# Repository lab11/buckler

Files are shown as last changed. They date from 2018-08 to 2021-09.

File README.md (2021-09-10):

Berkeley Buckler
================



A development board for teaching embedded systems.

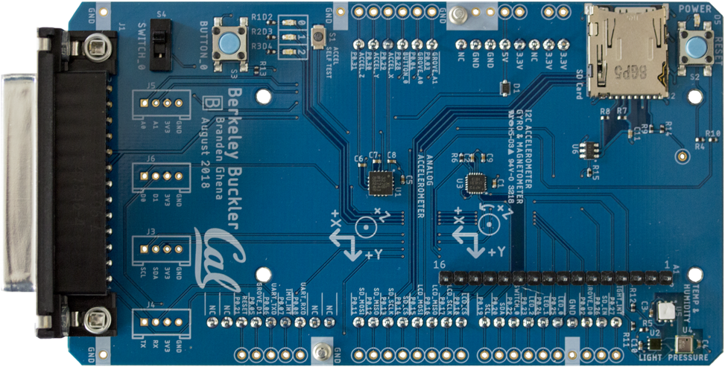
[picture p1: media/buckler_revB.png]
Buckler PCB


### Getting Started

 1. Clone this repository and update the submodule

```
  $ git clone https://github.com/lab11/buckler.git --recursive
  $ git subomdule update --init --recursive
```

 2. Build an example application

```
  $ cd software/apps/blink/
  $ make
```

You should see results similar to

```
BUILD OPTIONS:
  Chip        nrf52832
  RAM         64 kB
  FLASH       512 kB
  SDK         15
  SoftDevice  s132 6.0.0
  Board       Buckler_revB

 DIR        _build
 CC main.c ...
 ... (many more CCs) ...
 LD _build/blink_sdk15_s132.elf
 HEX _build/blink_sdk15_s132.hex
 BIN _build/blink_sdk15_s132.hex
 SIZE _build/blink_sdk15_s132.elf
 text    data    bss     dec    hex   filename
 37672   2548   2624   42844   a75c   _build/blink_sdk15_s132.elf
```

 3. Load the example application (be sure to connect your Buckler board)

```
  $ make flash
```

The three LEDS (red, yellow, and blue) on Buckler should begin a blinking
sequence.

### Build Options

Several make directives exist for convenience of performing common operations.

 * **flash** - Upload code to the attached board over JTAG. Also builds code if
               necessary.
 * **rtt** - Open two additional terminals, one starting a JTAG connection and
             the other with an RTT terminal.
 * **gdb** - Open two additional terminals, one starting a GDB server and the
		     the other with a GDB session.
 * **debug** - Build application in unoptimized debug mode (with `-g` and `-O0`).
 * **flash_debug** - Upload debug version of code to the attached board over JTAG.
				     Also builds the debug version of code if necessary.
 * **erase** - Erase all code from the attached board over JTAG.
 * **flash_softdevice** - Upload the appropriate softdevice to the board over JTAG.
						  `make flash` automatically runs this command.
 * **clean** - Remove all built output.
 * **size** - Print size of built application text and data segments.
 * **lst** - Generate an assembly listing of the built code.

### Directory Structure

```
├── hardware
│   └── <Various hardware revisions>
│       ├── <PDF version of schematic and layout>
│       ├── <Eagle schematic and layout files>
│       └── <Zipped assembly files>
├── media
│   └── <Images used in repo>
└── software
    ├── apps
    │   └── <Various applications>
    │       ├── <Code for application>
    │       └── <Makefile for application>
    ├── boards
    │   └── <Board-specific headers and Makefiles>
    ├── libraries
    │   └── <Various libraries>
    ├── nrf5x-base
    │   └── <Submodule: build tools and files for nRF projects>
    └── tools
        └── <Tools for Travis-CI use>
```

### Project Repositories

If you are using Buckler for a project, we recommend you include it as a
submodule in your own repository. An example of how to do so can be found in:
[buckler-external-repo](https://github.com/brghena/buckler-external-repo)

### Software Requirements

In order to get code compiling and loading over JTAG, you'll need at least two tools.

**JLinkExe** should be installed from [here](https://www.segger.com/downloads/jlink).
You want to the "J-Link Software and Documentation Pack". There are various packages
available depending on operating system.

**arm-none-eabi-gcc** is the cross-compiler version of GCC for building embedded ARM code.

  MacOS:
  ```
  $ brew tap ARMmbed/homebrew-formulae && brew update && brew install arm-none-eabi-gcc
  ```

  Ubuntu:
  ```
  $ sudo add-apt-repository ppa:team-gcc-arm-embedded/ppa && sudo apt update && sudo apt install gcc-arm-embedded
  ```

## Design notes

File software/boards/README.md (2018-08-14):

Boards
======

Platform-specific configurations and headers.

 * [Buckler revision A](../../hardware/rev_a/) - Buckler development shield revision A (obsolete)
 * [Buckler revision B](../../hardware/rev_b/) - Buckler development shield for [nRF52DK](http://infocenter.nordicsemi.com/index.jsp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)

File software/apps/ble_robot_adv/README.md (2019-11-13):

BLE Robot Template with Advertisements
================

Framework for using BLE advertisements + Kobuki
When button pressed, robot turns, and sends gyro readings over BLE advertisements

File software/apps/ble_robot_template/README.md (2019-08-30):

BLE Robot Template
================

Framework for using BLE + Kobuki

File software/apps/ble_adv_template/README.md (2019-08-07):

BLE Advertisement Template
===================

Starting point for creating a BLE advertisement application. This example uses
the Berkeley Buckler.

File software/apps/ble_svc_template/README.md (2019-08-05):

BLE Service Example
===================

This example code creates a custom service with readable and writable
characteristics which can be interacted with by a BLE master (such as a
smartphone).

The service and characteristic control LED0. Writing a 0x01 to the
characteristic turns the LED on, writing a 0x00 turns it off.

Using this application is essentially the same as any other Buckler app, with
`make flash` loading the application code and `make rtt` opening the RTT output
viewer.

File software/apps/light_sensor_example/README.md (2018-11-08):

Light Sensor Example
====================

Example that reads the MAX44009 light sensor. This uses the example code in
`libraries/max44009/` which was adapted from
[Permamote](https://github.com/lab11/permamote). The sensor data is read over
I2C.

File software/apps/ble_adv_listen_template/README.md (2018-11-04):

BLE RX Example
==============

Receives BLE advertisements. Advertisements are broadcast transmissions used to
discover the device which can also include up to 23 bytes of arbitrary payload
data.

This app can receive advertisements from anything, but is particularly looking
for another Buckler running the BLE TX Example application.

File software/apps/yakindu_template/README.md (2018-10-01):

Yakindu Template
================

Framework for using code generated by Yakindu statecharts.

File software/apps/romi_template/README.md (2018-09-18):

Robot Template
==============

Starting point for creating robot control code. This example uses the Kobuki
robot as well as the Berkeley Buckler.

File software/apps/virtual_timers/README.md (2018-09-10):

Virtual Timers
==============

The goal of this lab is to write a virtual timer library. You will use
one hardware timer to create a timer library that handles any number of timers.

The lab in order:
0) Read the timer and print it

1) Set up a single hardware timer interrupt and handle that interrupt

2) Create a timer library that can handle one timer at a time (with linked list)
    - Calculate time required for a time in ms and set up the timer
    - Insert into linked list
    - Call the callback function using function pointers

3) Add repeated mode to the timer library

4) Make two timers
    - Handle timers created out of earliest deadline order

5) Make N timers

6) Check for correctness in all cases
    - N timers firing very close to the same time (no timers should be dropped)
    - Add a very short timer to the list (does it keep firing?)
    - Remove timers from the list (do other timers keep firing?)

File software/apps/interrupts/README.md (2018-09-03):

Interrupts
=====

This is the starting application for Chapter 5 of the lab manual. The goal
is to explore and understand interrupts and related concepts such as wait for interrupt (WFI()), interrupt latency,
and interrupt priority/preemption/nesting.

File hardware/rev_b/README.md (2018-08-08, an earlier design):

Hardware Files
==============

The Berkeley Buckler was created in
[Eagle](https://www.autodesk.com/products/eagle/overview) and the `buckler.sch`
and `buckler.brd` files are Eagle schematic and board files respectively.
Schematic and board files can be viewed without Eagle in `buckler.pdf`.
`buckler_bom.xlsx` is the Bill of Materials (list of parts). It is also
provided as `txt` and `csv` files for convenience.

## Changes from prior revision
 * Change base board from the nRF52840DK to the nRF52DK (based on the nRF52832) due to availability
     * Reduced number of buttons, switches, and grove headers to deal with reduced number of pins
     * Removed connection to SD card detect signal to deal with reduced number of pins
     * Re-mapped signals to development kit pins
 * Made text bigger and added more test points
 * Shrunk board size a little

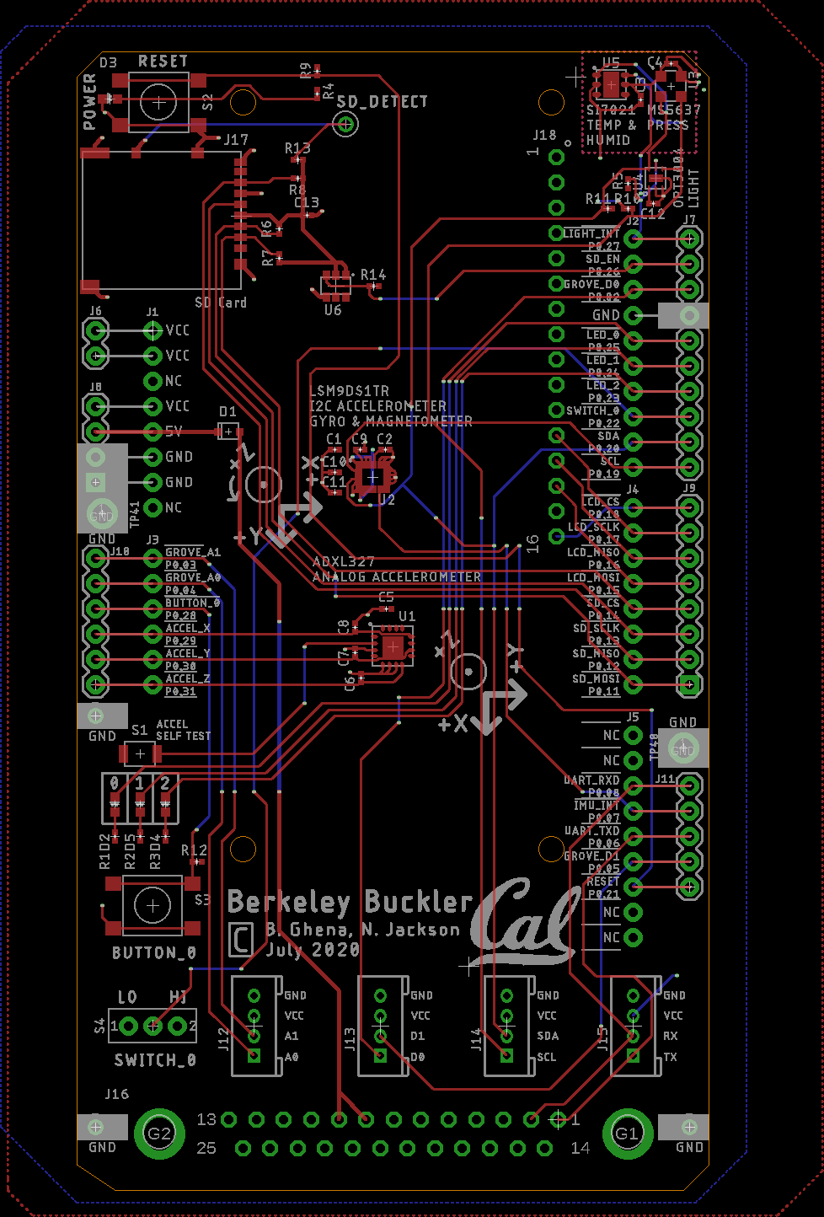
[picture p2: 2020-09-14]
hardware/rev_c/buckler_pcb.png

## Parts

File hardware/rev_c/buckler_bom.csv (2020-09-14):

# Bill of Materials
# Converted from {}
# Generated by bom_to_text.py
#
Qty | Value | Device | Package | Parts | Description | DESCRIPTION | DIGIKEY | MANUFACTURER | MOUSER | MPN
1 |  | DIODE_SCHOTTKYSOD323 | SOD323 | D1 |  | DIODE SCHOTTKY 30V 500MA SOD323 | B0530WS-FDICT-ND | Diodes Incorporated |  | B0530WS-7-F
4 |  | GROVE-CONNECTOR-DIP(4P-2.0) | HW4-2.0 | J12, J13, J14, J15 | 320110033 | Grove - Universal 4 pin connector |  | Seeed Studio | 713-110990030 | 110990030
1 |  | M02PTH | 1X02 | J6 | Header 2 |  | S1011EC-02-ND
1 |  | M04PTH | 1X04 | J8 | Header 4 |  | S1011EC-04-ND
1 |  | M05PTH | 1X05 | J11 | Header 5 |  | S1011EC-05-ND
2 |  | M06SIP | 1X06 | J3, J10 | Header 6 |  | S1011EC-06-ND
3 |  | M081X08 | 1X08 | J1, J4, J9 | Header 8 |  | S1011EC-08-ND
1 |  | M09PTH | 1X09 | J5 | Header 9 |  | S1011EC-09-ND
2 | M10 | M10 | M10 | J2, J7 | Header 10 |  | S1011EC-10-ND
2 | 100k | RESISTOR0402_RES | 0402_RES | R13, R14 | Resistor | RES SMD 100K OHM 1% 1/5W 0402 | 541-100KYCT-ND | Vishay Dale |  | CRCW0402100KFKEDHP
10 | 100nF | CAPACITOR0402_CAP | 0402_CAP | C3, C4, C5, C6, C7, C8, C9, C10, C11, C12 | SMD Capacitor | CAP CER 0.1UF 16V X7R 0402 | 490-4759-1-ND | Murata |  | GCM155R71C104KA55D
8 | 10k | RESISTOR0402_RES | 0402_RES | R5, R6, R7, R8, R9, R10, R11, R12 | Resistor | RES SMD 10K OHM 1% 1/16W 0402 | 1276-3431-1-ND | Samsung Electro-Mechanics |  | RC1005F103CS
2 | 10nF | CAPACITOR0402_CAP | 0402_CAP | C1, C2 | SMD Capacitor | CAP CER 10000PF 25V X7R 0402 | 399-1279-1-ND | KEMET |  | C0402C103J3RACTU
4 | 1k | RESISTOR0402_RES | 0402_RES | R1, R2, R3, R4 | Resistor | RES SMD 1K OHM 1% 1/16W 0402 | RMCF0402FT1K00CT-ND | Stackpole Electronics |  | RMCF0402FT1K00
1 | 4.7uF | CAPACITOR0402_CAP | 0402_CAP | C13 | SMD Capacitor | CAP CER 4.7UF 10V X5R 0402 | 1276-1480-1-ND | Samsung Electro-Mechanics |  | CL05A475KP5NRNC
1 | ADXL327 | ADXL327 | LFCSP-16 | U1 | ADXL327 3-Axis Analog Accelerometer | ACCELEROMETER 2G ANALOG 16LFCSP | ADXL327BCPZ-ND | Analog Devices Inc. |  | ADXL327BCPZ
1 | B3U-1000P | B3U-1000P | B3U-1000P | S1 | Switch | SWITCH TACTILE SPST-NO 0.05A 12V | SW1020CT-ND | Omron |  | B3U-1000P
1 | BLUE | LED0603 | LED-0603 | D4 | LED | LED BLUE CLEAR SMD | 160-1837-1-ND | Lite-On Inc. |  | LTST-C194TBKT
1 | DB25_5747846 | DB25_5747846 | DB25_5747846 | J16 |  | CONN D-SUB RCPT 25POS R/A SOLDER | A32126-ND | TE Connectivity AMP Connectors |  | 5747846-4
1 | DM3AT-SF-PEJM5 | DM3AT-SF-PEJM5 | DM3AT-SF-PEJM5 | J17 | CONN MICRO SD R/A PUSH-PUSH SMD | CONN MICRO SD CARD PUSH-PUSH R/A | HR1964CT-ND | Hirose Electric Co Ltd |  | DM3AT-SF-PEJM5
1 | GREEN | LED0603 | LED-0603 | D3 | LED | LED GREEN CLEAR CHIP SMD | 160-1435-1-ND | Lite-On Inc. |  | LTST-C190KGKT
1 | LSM9DS1TR | LSM9DS1TR | LGA-24_3X3P5X1_STM | U2 |  |  | 497-14946-1-ND |  |  | LSM9DS1TR
1 | MS5637-02BA03 | MS5637-02BA03 | 4-SMD | U3 | low power pressure sensor | SENSOR 17.4PSIA I2C 24B 4-QFN | 223-1199-1-ND | TE CONNECTIVITY |  | MS563702BA03-50
1 | NHD-0216KZWSERIAL | NHD-0216KZWSERIAL | NHD-0216KZW | J18 |  |  | NHD-0216KZW-AG5-ND, 952-3305-ND, 952-1862-ND
1 | OPT3004DNPR | OPT3004DNPR | DNP0006A | U4 |  |  | 296-53402-1-ND | Texas Instruments |  | OPT3004DNPR
2 | PTS645SM43SMTR92 | PTS645SM43SMTR92 | PTS645 | S2, S3 | Tactile Switch SPST-NO Top Actuated Surface Mount | SWITCH TACTILE SPST-NO 0.05A 12V | CKN9112CT-ND | C&K |  | PTS645SM43SMTR92 LFS
1 | RED | LED0603 | LED-0603 | D2 | LED | LED RED CLEAR CHIP SMD | 160-1436-1-ND | Lite-On Inc. |  | LTST-C190KRKT
1 | SI7021-A20-GM1 | SI7021-A20-GM1 | DFN-6/3MM | U5 | IC TEMP SENSOR RH 2% DFN | SENS HUMI/TEMP 3.6V I2C 3% 6DFN | 336-3141-ND | Silicon Labs | 634-SI7021-A20-GM1 | SI7021-A20-GM1
1 | SIP32510 | SIP32510 | TSOT23-6 | U6 | Load switch, slew rate controlled. By Vishay | IC LOAD SWITCH SOT23-6 | SIP32510DT-T1-GE3CT-ND | Vishay |  | SIP32510DT-T1-GE3
2 | TEST_POINT_0.078IN | TEST_POINT_0.078IN | TESTPOINT_0.078IN | TP40, TP41 |  | TERM TURRET SINGLE L=4.75MM TIN | 36-1520-2-ND | Keystone Electronics |  | 1520-2
1 | TE_SSA12/SPDT | TE_SSA12/SPDT | TE_SSA12/SPDT | S4 | SWITCH SLIDE SPDT 2POS SSA SER | SWITCH SLIDE SPDT 100MA 30V | 450-1602-ND | TE Connectivity ALCOSWITCH Switches |  | SSA12
1 | YELLOW | LED0603 | LED-0603 | D5 | LED | LED YELLOW CLEAR CHIP SMD | 160-1437-1-ND | Lite-On Inc. |  | LTST-C190KSKT

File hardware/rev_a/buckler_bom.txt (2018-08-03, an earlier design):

# Bill of Materials
# Converted from buckler_bom.xlsx
# Generated by bom_to_text.py
#
# # Bill of Materials                                                                                                                                                                                                                                                                                                                                                                                                                                                                                                                                                                                                                                                                                             
# # Converted from {}                                                                                                                                                                                                                                                                                                                                                                                                                                                                                                                                                                                                                                                                                             
# # Generated by bom_to_text.py                                                                                                                                                                                                                                                                                                                                                                                                                                                                                                                                                                                                                                                                                   
# #                                                                                                                                                                                                                                                                                                                                                                                                                                                                                                                                                                                                                                                                                                               
#                                                                                                                                                                                                                                                                                                                                                                                                                                                                                                                                                                                                                                                                                                                 
# Qty                            Value               Device                       Package            Parts                                                                                                                                                                                                                                              Description                                        DESCRIPTION                                                                              DIGIKEY                         DIGIKEY1            DIGIKEY2       DIGIKEY3       DIGIKEY4       DIGIKEY5       DIGIKEY6       MANUFACTURER                         MOUSER              MPN                   VALUE
1                                NHD-0216KZWSERIAL   NHD-0216KZWSERIAL            NHD-0216KZW        A1                                                                                                                                                                                                                                                                                                                                                                                             NHD-0216KZW-AG5-ND,952-3305-ND  NHD-0216KZW-AG5-ND  952-3305-ND                                                                                                                                               
1                                10nF                CAPACITOR0402_CAP            0402_CAP           C1                                                                                                                                                                                                                                                 SMD Capacitor                                      CAP CER 10000PF 25V X7R 0402                                                             399-1279-1-ND                                                                                                                  KEMET                                                    C0402C103J3RACTU      
8                                100nF               CAPACITOR0402_CAP            0402_CAP           C2, C3, C4, C5, C6, C7, C8, C9                                                                                                                                                                                                                     SMD Capacitor                                      CAP CER 0.1UF 16V X7R 0402                                                               490-4759-1-ND                                                                                                                  Murata                                                   GCM155R71C104KA55D    
1                                1uF                 CAPACITOR0402_CAP            0402_CAP           C10                                                                                                                                                                                                                                                SMD Capacitor                                      CAP CER 1UF 10V X6S 0402                                                                 1276-6805-1-ND                                                                                                                 Samsung Electro-Mechanics                                CL05X105KP5NNNC       
1                                4.7uF               CAPACITOR0402_CAP            0402_CAP           C11                                                                                                                                                                                                                                                SMD Capacitor                                      CAP CER 4.7UF 10V X5R 0402                                                               1276-1480-1-ND                                                                                                                 Samsung Electro-Mechanics                                CL05A475KP5NRNC       
1                                                    DIODE_SCHOTTKYSOD323         SOD323             D1                                                                                                                                                                                                                                                                                                    DIODE SCHOTTKY 30V 500MA SOD323                                                          B0530WS-FDICT-ND                                                                                                               Diodes Incorporated                                      B0530WS-7-F           
1                                RED                 LED0603                      LED-0603           D2                                                                                                                                                                                                                                                 LED                                                LED RED CLEAR CHIP SMD                                                                   160-1436-1-ND                                                                                                                  Lite-On Inc.                                             LTST-C190KRKT         
1                                YELLOW              LED0603                      LED-0603           D3                                                                                                                                                                                                                                                 LED                                                LED YELLOW CLEAR CHIP SMD                                                                160-1437-1-ND                                                                                                                  Lite-On Inc.                                             LTST-C190KSKT         
1                                BLUE                LED0603                      LED-0603           D4                                                                                                                                                                                                                                                 LED                                                LED BLUE CLEAR SMD                                                                       160-1837-1-ND                                                                                                                  Lite-On Inc.                                             LTST-C194TBKT         
1                                GREEN               LED0603                      LED-0603           D5                                                                                                                                                                                                                                                 LED                                                LED GREEN CLEAR CHIP SMD                                                                 160-1435-1-ND                                                                                                                  Lite-On Inc.                                             LTST-C190KGKT         
1                                DB25_5747846        DB25_5747846                 DB25_5747846       J1                                                                                                                                                                                                                                                                                                    CONN D-SUB RCPT 25POS R/A SOLDER                                                         A32126-ND                                                                                                                      TE Connectivity AMP Connectors                           5747846-4             
1                                DM3AT-SF-PEJM5      DM3AT-SF-PEJM5               DM3AT-SF-PEJM5     J2                                                                                                                                                                                                                                                 CONN MICRO SD R/A PUSH-PUSH SMD                    CONN MICRO SD CARD PUSH-PUSH R/A                                                         HR1964CT-ND                                                                                                                    Hirose Electric Co Ltd                                   DM3AT-SF-PEJM5        
6                                4P-2.0              GROVE-CONNECTOR-DIP(4P-2.0)  HW4-2.0            J3, J4, J5, J6, J7, J8                                                                                                                                                                                                                             320110033                                          Grove - Universal 4 pin connector                                                                                                                                                                                       Seeed Studio                         713-110990030       110990030             4P-2.0
1                                NRF52840DK_SHIELD   NRF52840DK_SHIELD            NRF52840DK_SHIELD  J9                                                                                                                                                                                                                                                 Shield for the PCA10056 nRF52840 Development Kit   Headers for nRF52840DK. There are 6 separate headers to be installed through the board.                                  S1011EC-10-ND       S1011EC-08-ND  S1011EC-08-ND  S1011EC-08-ND  S1011EC-06-ND  S2011EC-09-ND                                                                                 
4                                1k                  RESISTOR0402_RES             0402_RES           R1, R2, R3, R4                                                                                                                                                                                                                                     Resistor                                           RES SMD 1K OHM 1% 1/16W 0402                                                             RMCF0402FT1K00CT-ND                                                                                                            Stackpole Electronics                                    RMCF0402FT1K00        
10                               10k                 RESISTOR0402_RES             0402_RES           R5, R6, R7, R8, R9, R10, R11, R12, R13, R14                                                                                                                                                                                                        Resistor                                           RES SMD 10K OHM 1% 1/16W 0402                                                            1276-3431-1-ND                                                                                                                 Samsung Electro-Mechanics                                RC1005F103CS          
2                                100k                RESISTOR0402_RES             0402_RES           R15, R16                                                                                                                                                                                                                                           Resistor                                           RES SMD 100K OHM 1% 1/5W 0402                                                            541-100KYCT-ND                                                                                                                 Vishay Dale                                              CRCW0402100KFKEDHP    
1                                B3U-1000P           B3U-1000P                    B3U-1000P          S1                                                                                                                                                                                                                                                 Switch                                             SWITCH TACTILE SPST-NO 0.05A 12V                                                         SW1020CT-ND                                                                                                                    Omron                                                    B3U-1000P             
3                                PTS645SM43SMTR92    PTS645SM43SMTR92             PTS645             S2, S3, S4                                                                                                                                                                                                                                         Tactile Switch SPST-NO Top Actuated Surface Mount  SWITCH TACTILE SPST-NO 0.05A 12V                                                         CKN9112CT-ND                                                                                                                   C&K                                                      PTS645SM43SMTR92 LFS  
2                                TE_SSA12/SPDT       TE_SSA12/SPDT                TE_SSA12/SPDT      S5, S6                                                                                                                                                                                                                                             SWITCH SLIDE SPDT 2POS SSA SER                     SWITCH SLIDE SPDT 100MA 30V                                                              450-1602-ND                                                                                                                    TE Connectivity ALCOSWITCH Switches                      SSA12                 
42                               TEST_POINT_0.040IN  TEST_POINT_0.040IN           TESTPOINT_0.040IN  TP1, TP2, TP3, TP4, TP5, TP6, TP7, TP8, TP9, TP10, TP11, TP12, TP13, TP14, TP15, TP16, TP17, TP18, TP19, TP20, TP21, TP22, TP23, TP24, TP25, TP26, TP27, TP28, TP29, TP30, TP31, TP32, TP33, TP34, TP35, TP36, TP37, TP38, TP39, TP40, TP41, TP42  0.040in Test Point                                                                                                                          5001K-ND                                                                                                                                                                                                      
2                                TEST_POINT_0.078IN  TEST_POINT_0.078IN           TESTPOINT_0.078IN  TP43, TP44                                                                                                                                                                                                                                                                                            TERM TURRET SINGLE L=4.75MM TIN                                                          36-1520-2-ND                                                                                                                   Keystone Electronics                                     1520-2                
1                                ADXL327             ADXL327                      LFCSP-16           U1                                                                                                                                                                                                                                                 ADXL327 3-Axis Analog Accelerometer                ACCELEROMETER 2G ANALOG 16LFCSP                                                          ADXL327BCPZ-ND                                                                                                                 Analog Devices Inc.                                      ADXL327BCPZ           
1                                MAX44009            MAX44009                     UDFN-6-EXPOSED     U2                                                                                                                                                                                                                                                 low power ambient light sensor                     SENSOR AMBIENT LIGHT 6UTDFN                                                              MAX44009EDT+TCT-ND                                                                                                             Maxim Integrated                                         MAX44009EDT+T         
1                                MPU-9250            MPU-9250                     QFN-24/3MM         U3                                                                                                                                                                                                                                                 GYRO/ACCEL/COMPASS/9-AXIS                          IMU ACCEL/GYRO/MAG I2C/SPI 24QFN                                                         1428-1019-1-ND                                                                                                                 TDK InvenSense                                           MPU-9250              
1                                MS5637-02BA03       MS5637-02BA03                4-SMD              U4                                                                                                                                                                                                                                                 low power pressure sensor                          SENSOR 17.4PSIA I2C 24B 4-QFN                                                            223-1199-1-ND                                                                                                                  TE CONNECTIVITY                                          MS563702BA03-50       
1                                SI7021-A20-GM1      SI7021-A20-GM1               DFN-6/3MM          U5                                                                                                                                                                                                                                                 IC TEMP SENSOR RH 2% DFN                           SENS HUMI/TEMP 3.6V I2C 3% 6DFN                                                          336-3141-ND                                                                                                                    Silicon Labs                         634-SI7021-A20-GM1  SI7021-A20-GM1        
1                                SIP32510            SIP32510                     TSOT23-6           U6                                                                                                                                                                                                                                                 Load switch, slew rate controlled. By Vishay       IC LOAD SWITCH SOT23-6                                                                   SIP32510DT-T1-GE3CT-ND                                                                                                         Vishay                                                   SIP32510DT-T1-GE3

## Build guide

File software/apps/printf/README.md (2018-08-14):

printf App
==========

Example of using printf over RTT. To see output run `make rtt`

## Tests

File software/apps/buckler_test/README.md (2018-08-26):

Buckler Test App
================

Tests the functionality of Buckler. This is a combination of the blink, button,
printf, analog accelerometer, and i2c_imu apps at the moment, but should
eventually expand to include more tests.

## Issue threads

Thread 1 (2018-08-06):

Rev A Issues

brghena, 2018-08-06:
- [x] Add accelerometer axes (X, Y, Z) to silkscreen
- [x] Add female header for LCD
- [x] Do something about LCD header nearly intersecting with dev board header (possibly rotate the LCD 180 degrees)
    - Moved it 25 mil to the right to avoid collision
- [x] Check the footprint for the MPU-9250
- [x] Add probe points for P6

brghena, 2018-08-07:
- [ ] Give up on the nRF52840DK which has zero availability until December (down from having availability two weeks ago when we selected it) and switch to the nRF52DK (nRF52832)

Closed 2018-08-10.

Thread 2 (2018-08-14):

Rev B Issues

brghena, 2018-08-14:
- [x] Add silkscreen label for switch position high/low
- [x] Put IC part numbers on the silkscreen

brghena, 2018-08-24:
- [ ] Got the RX and TX pins reversed on the Kobuki connection (sigh). Totally fixable in hardware, but we should change it for future revisions.

brghena, 2018-08-28:
- [ ] 3v3 label is confusing since Vcc is actually less than 3 volts...

adkinsjd, 2018-09-19:
- [ ] Move the gyro/accel axis label out from under the screen

nealjack, 2020-07-23:
I just committed a fix for most of these issues. I'm not sure what "Use some labeling to show hole connection to the signals" means. Does that mean have silk lines connecting the parallel holes on the side of the board?

brghena, 2020-07-23:
It wasn't clear to some students that the holes were the same thing as the soldered pins. Probably safe to ignore. Alternatively a silkscreen line from the hole to the pin might be good if you think it's warranted.

Closed 2020-10-26.

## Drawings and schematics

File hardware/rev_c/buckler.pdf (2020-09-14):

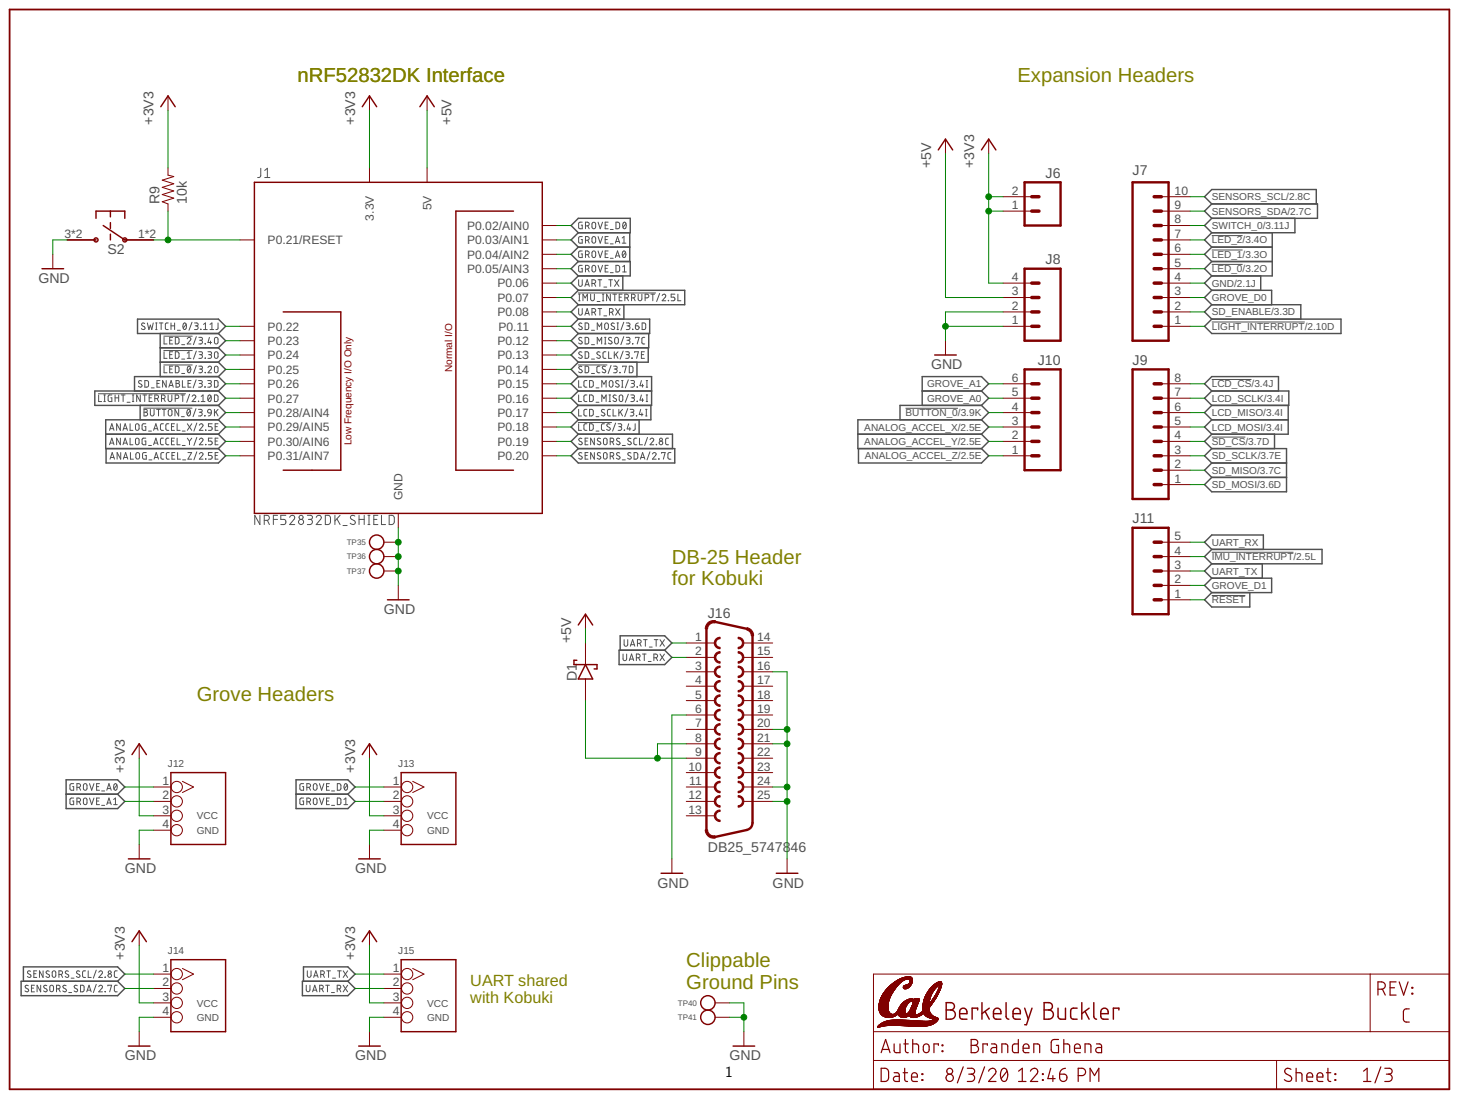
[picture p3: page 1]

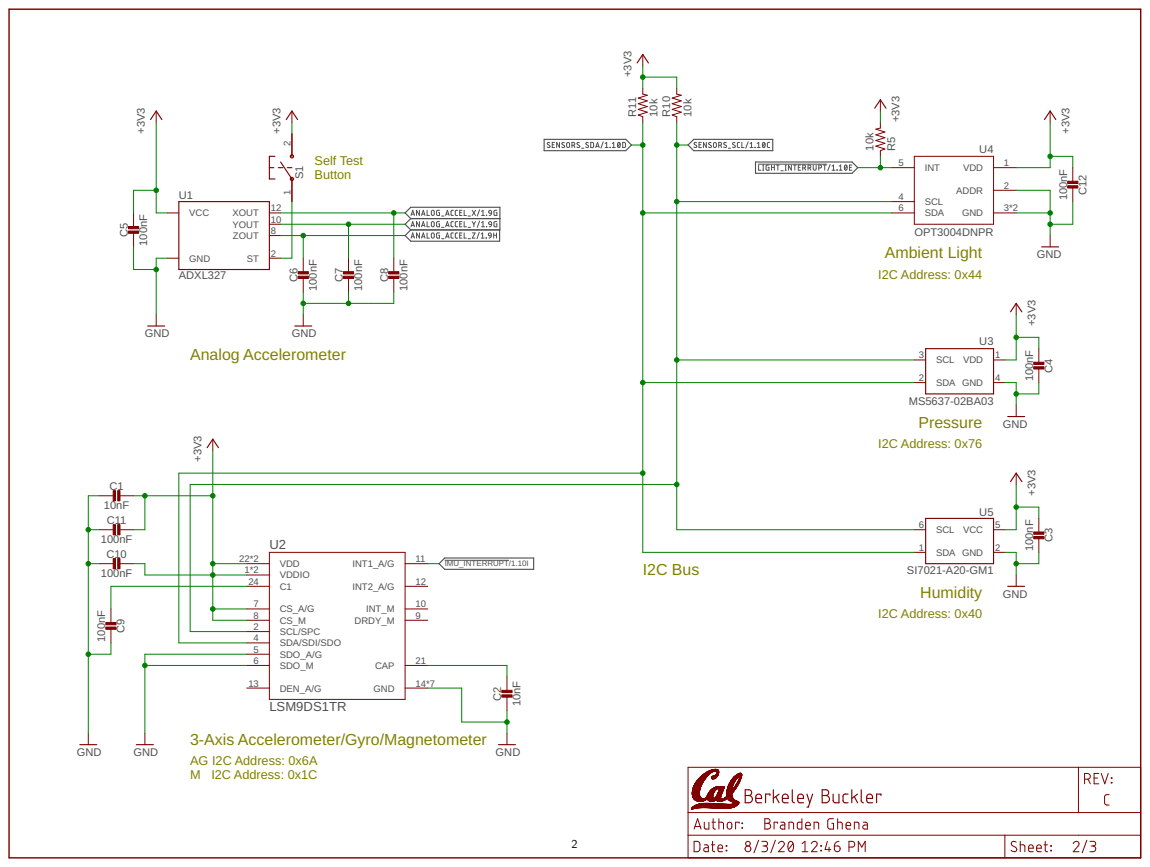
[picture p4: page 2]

# 4 GND

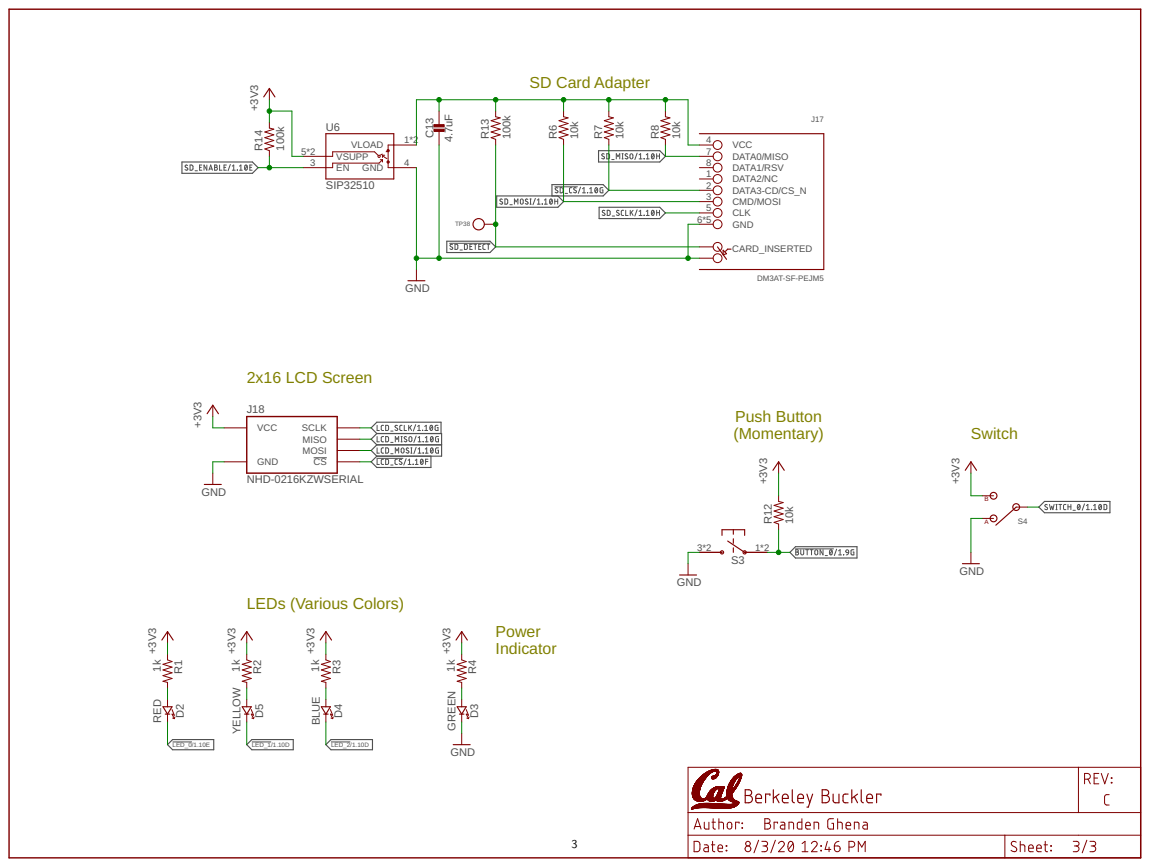
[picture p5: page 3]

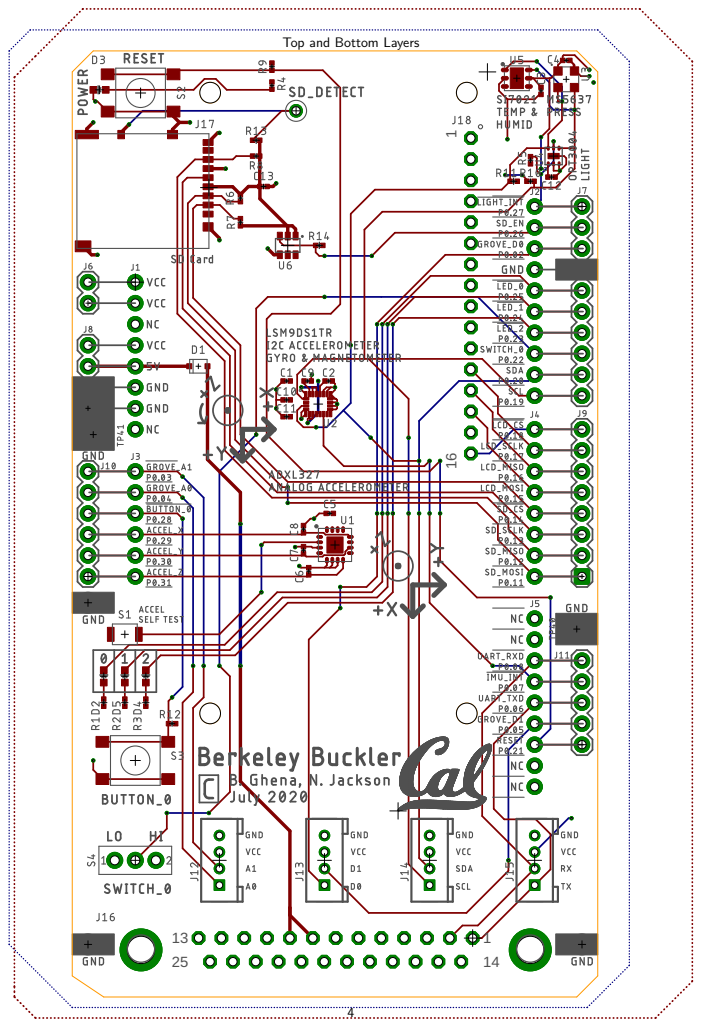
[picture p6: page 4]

Top and Bottom Layers

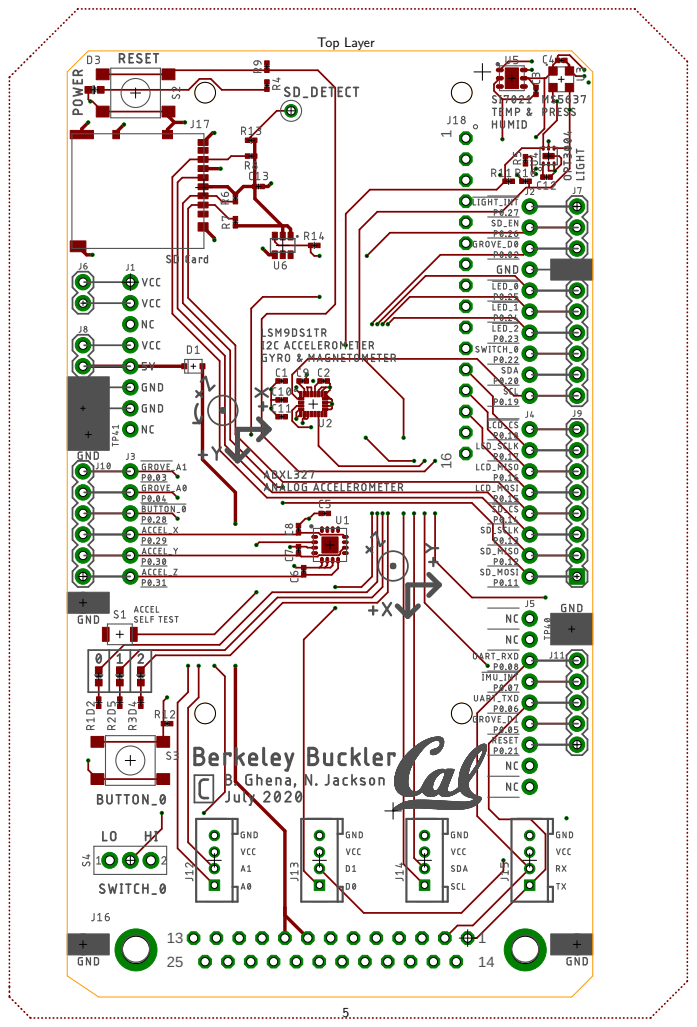
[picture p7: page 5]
Top Layer

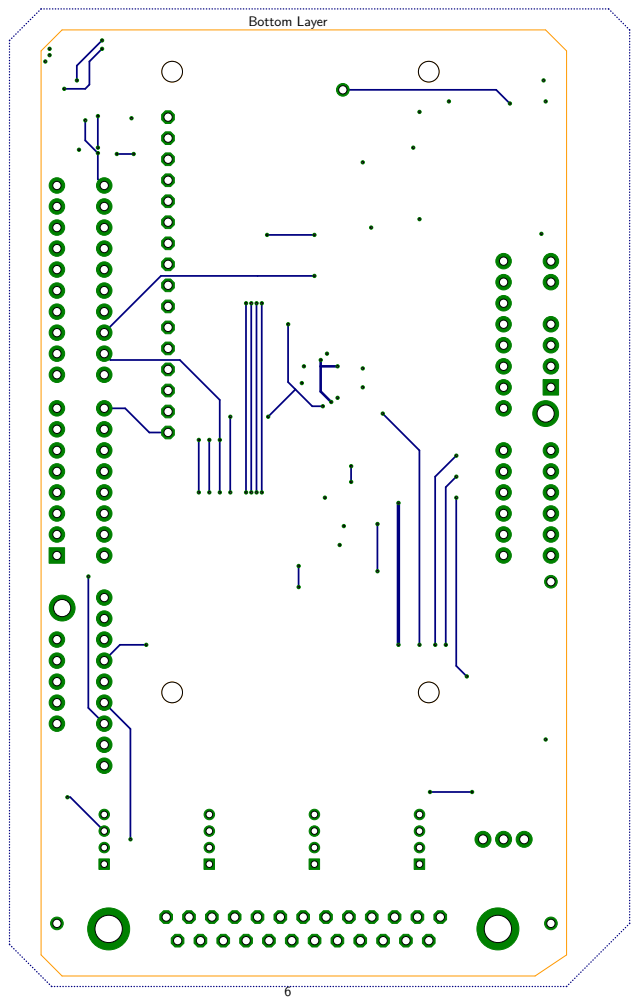
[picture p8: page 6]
Bottom Layer

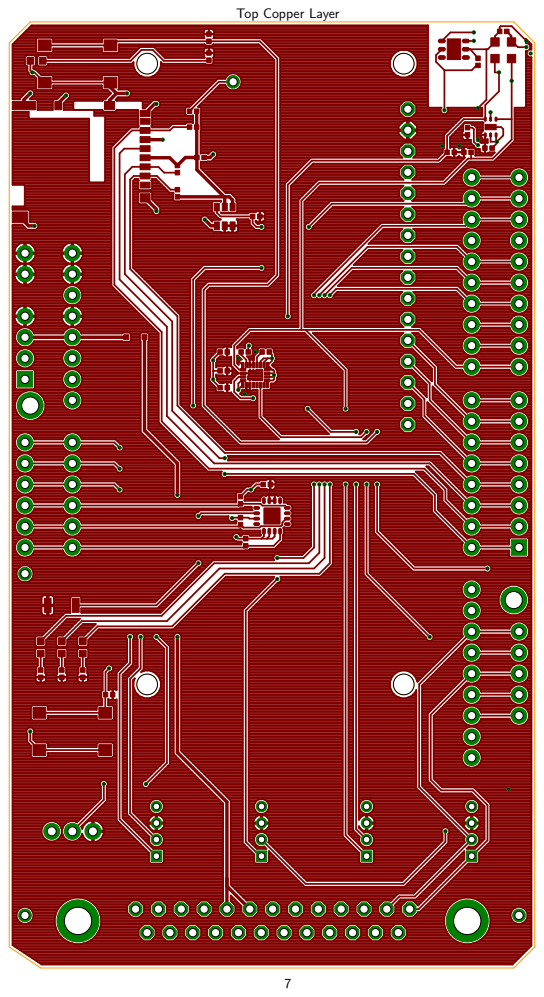
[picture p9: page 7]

Top Copper Layer

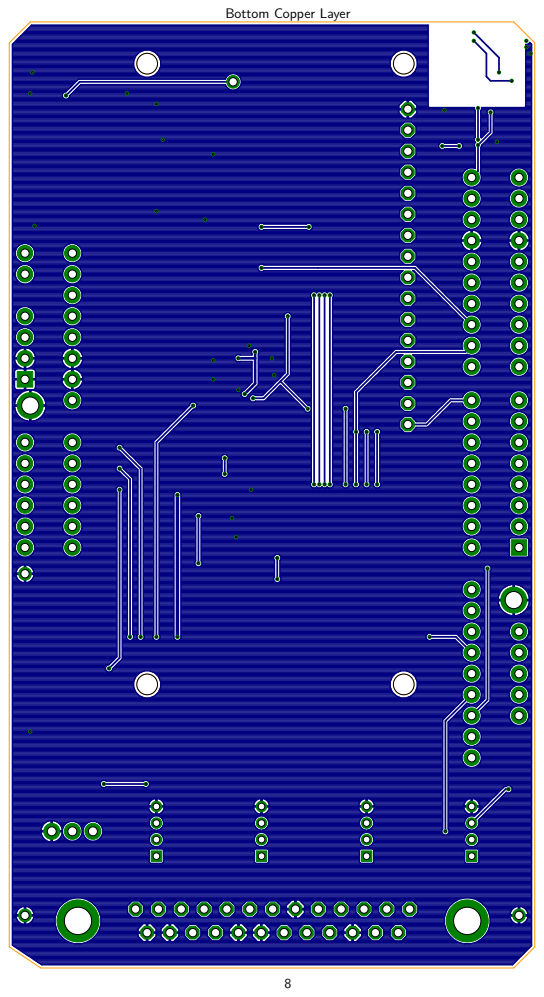
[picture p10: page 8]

Bottom Copper Layer

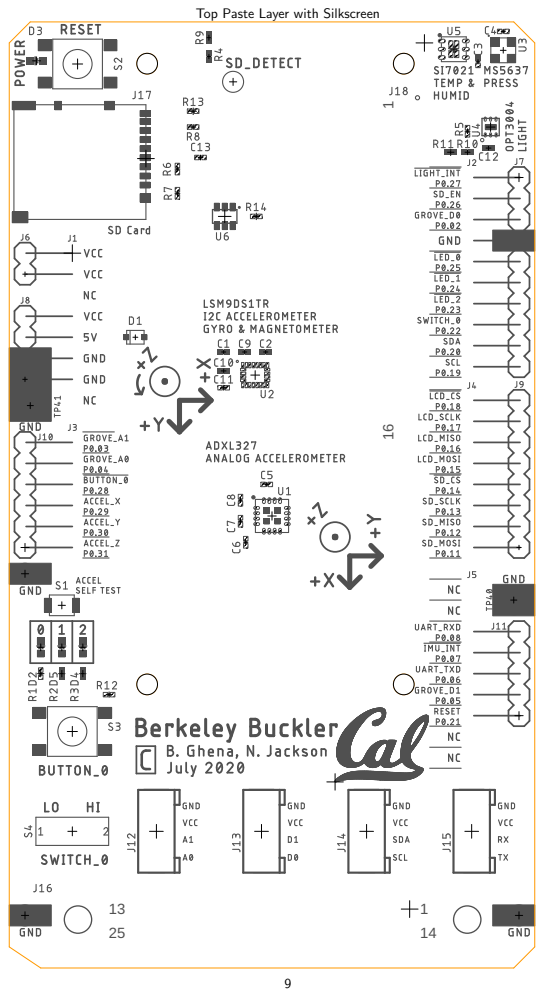
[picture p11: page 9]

Top Paste Layer with Silkscreen

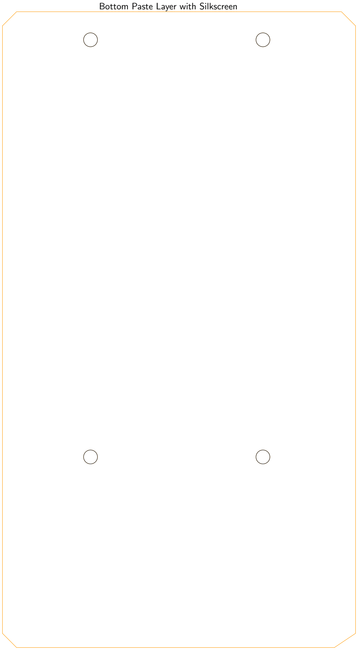
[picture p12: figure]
Bottom Paste Layer with Silkscreen
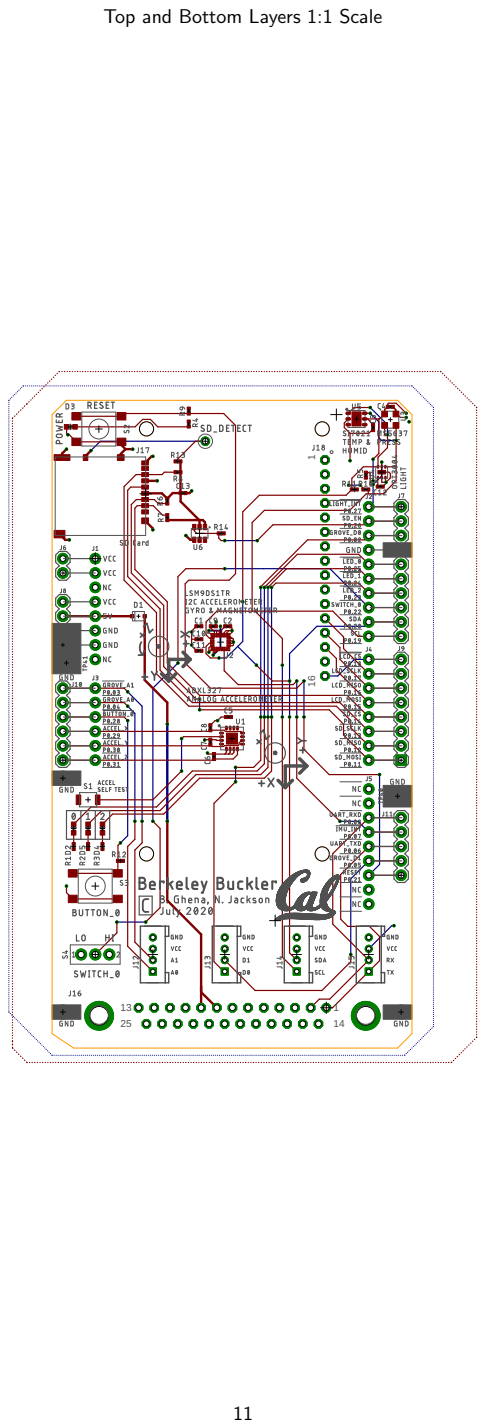
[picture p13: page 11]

Top and Bottom Layers 1:1 Scale

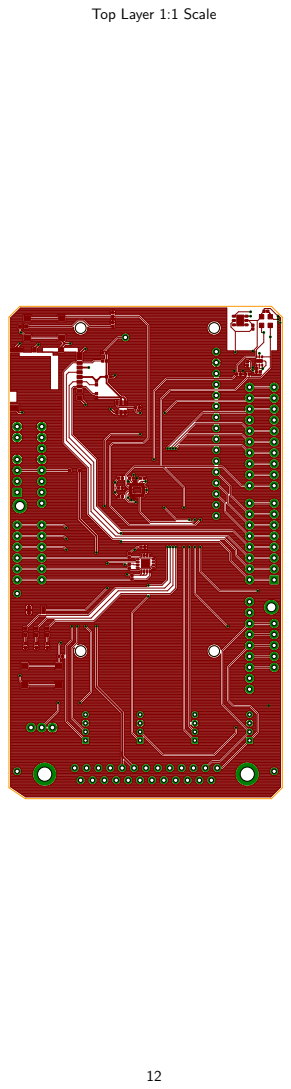
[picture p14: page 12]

Top Layer 1:1 Scale


Bottom Copper Layer 1:1 Scale

### buckler_bom

Qty Value | Device | Package
1 | DIODE_SCHOTTKYSOD323 | SOD323
4 | GROVE-CONNECTOR-DIP(4P-2.0) HW4-2.0
1 | M02PTH | 1X02
1 | M04PTH | 1X04
1 | M05PTH | 1X05
2 | M06SIP | 1X06
3 | M081X08 | 1X08
1 | M09PTH | 1X09
2 M10 | M10 | M10
2 100k | RESISTOR0402_RES | 0402_RES
10100nF | CAPACITOR0402_CAP | 0402_CAP
8 10k | RESISTOR0402_RES | 0402_RES
2 10nF | CAPACITOR0402_CAP | 0402_CAP
4 1k | RESISTOR0402_RES | 0402_RES
1 4.7uF | CAPACITOR0402_CAP | 0402_CAP
1 ADXL327 | ADXL327 | LFCSP-16
1 B3U-1000P | B3U-1000P | B3U-1000P
1 BLUE | LED0603 | LED-0603
1 DB25_5747846 | DB25_5747846 | DB25_5747846
1 DM3AT-SF-PEJM5 | DM3AT-SF-PEJM5 | DM3AT-SF-PEJM5
1 GREEN | LED0603 | LED-0603
1 LSM9DS1TR | LSM9DS1TR | LGA-24_3X3P5X1_STM
1 MS5637-02BA03 | MS5637-02BA03 | 4-SMD
1 NHD-0216KZWSERIAL NHD-0216KZWSERIAL | NHD-0216KZW
1 OPT3004DNPR | OPT3004DNPR | DNP0006A
2 PTS645SM43SMTR92 PTS645SM43SMTR92 | PTS645
1 RED | LED0603 | LED-0603
1 SI7021-A20-GM1 | SI7021-A20-GM1 | DFN-6/3MM
1 SIP32510 | SIP32510 | TSOT23-6
2 TEST_POINT_0.078IN TEST_POINT_0.078IN | TESTPOINT_0.078IN
1 TE_SSA12/SPDT | TE_SSA12/SPDT | TE_SSA12/SPDT
1 YELLOW | LED0603 | LED-0603

### buckler_bom

Parts | Description
D1
J12, J13, J14, J15 | 320110033
J6 | Header 2
J8 | Header 4
J11 | Header 5
J3, J10 | Header 6
J1, J4, J9 | Header 8
J5 | Header 9
J2, J7 | Header 10
R13, R14 | Resistor
C3, C4, C5, C6, C7, C8, C9, C10, C11, C12 SMD Capacitor
R5, R6, R7, R8, R9, R10, R11, R12 | Resistor
C1, C2 | SMD Capacitor
R1, R2, R3, R4 | Resistor
C13 | SMD Capacitor
U1 | ADXL327 3-Axis Analog Accelerometer
S1 | Switch
D4 | LED
J16
J17 | CONN MICRO SD R/A PUSH-PUSH SMD
D3 | LED
U2
U3 | low power pressure sensor
J18
U4
S2, S3 | Tactile Switch SPST-NO Top Actuated Surface Mount
D2 | LED
U5 | IC TEMP SENSOR RH 2% DFN
U6 | Load switch, slew rate controlled. By Vishay
TP40, TP41
S4 | SWITCH SLIDE SPDT 2POS SSA SER
D5 | LED

### buckler_bom

DESCRIPTION | DIGIKEY
DIODE SCHOTTKY 30V 500MA SOB0530WS-FDICT-ND Grove - Universal 4 pin connector
| S1011EC-02-ND S1011EC-04-ND S1011EC-05-ND S1011EC-06-ND S1011EC-08-ND S1011EC-09-ND S1011EC-10-ND

RES SMD 100K OHM 1% 1/5W 040541-100KYCT-ND CAP CER 0.1UF 16V X7R 0402 490-4759-1-ND
RES SMD 10K OHM 1% 1/16W 0401276-3431-1-ND
CAP CER 10000PF 25V X7R 0402 399-1279-1-ND
RES SMD 1K OHM 1% 1/16W 0402RMCF0402FT1K00CT-ND CAP CER 4.7UF 10V X5R 0402 1276-1480-1-ND ACCELEROMETER 2G ANALOG 1ADXL327BCPZ-ND SWITCH TACTILE SPST-NO 0.05A SW1020CT-ND
LED BLUE CLEAR SMD | 160-1837-1-ND
CONN D-SUB RCPT 25POS R/A S A32126-ND
CONN MICRO SD CARD PUSH-PUHR1964CT-ND LED GREEN CLEAR CHIP SMD 160-1435-1-ND
| 497-14946-1-ND
SENSOR 17.4PSIA I2C 24B 4-QFN223-1199-1-ND
| NHD-0216KZW-AG5-ND, 952-3305-ND, 952-1862-ND 296-53402-1-ND

SWITCH TACTILE SPST-NO 0.05A CKN9112CT-ND
LED RED CLEAR CHIP SMD 160-1436-1-ND
SENS HUMI/TEMP 3.6V I2C 3% 6 336-3141-ND
IC LOAD SWITCH SOT23-6 | SIP32510DT-T1-GE3CT-ND
TERM TURRET SINGLE L=4.75MM36-1520-2-ND
SWITCH SLIDE SPDT 100MA 30V 450-1602-ND
LED YELLOW CLEAR CHIP SMD 160-1437-1-ND

### buckler_bom

MANUFACTURER | MOUSER | MPN
Diodes Incorporated | | B0530WS-7-F
Seeed Studio | 713-110990030 | 110990030
Vishay Dale | CRCW0402100KFKEDHP
Murata | GCM155R71C104KA55D
Samsung Electro-Mechanics | RC1005F103CS
KEMET | C0402C103J3RACTU
Stackpole Electronics | RMCF0402FT1K00
Samsung Electro-Mechanics | CL05A475KP5NRNC
Analog Devices Inc. | ADXL327BCPZ
Omron | B3U-1000P
Lite-On Inc. | LTST-C194TBKT
TE Connectivity AMP Connectors | 5747846-4
Hirose Electric Co Ltd | DM3AT-SF-PEJM5
Lite-On Inc. | LTST-C190KGKT
| LSM9DS1TR
TE CONNECTIVITY | MS563702BA03-50
Texas Instruments | OPT3004DNPR
C&K | PTS645SM43SMTR92 LFS
Lite-On Inc. | LTST-C190KRKT
Silicon Labs | 634-SI7021-A20-GM1 SI7021-A20-GM1
Vishay | SIP32510DT-T1-GE3
Keystone Electronics | 1520-2
TE Connectivity ALCOSWITCH Switches | SSA12
Lite-On Inc. | LTST-C190KSKT

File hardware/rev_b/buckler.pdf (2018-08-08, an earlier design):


2 3-Axis Accelerometer/Gyro/Magnetometer I2C Address: 0x68; Humidity Pressure Ambient Light Analog Accelerometer; I2C Address: 0x4A I2C Address: 0x76 I2C Address: 0x40 Self Test Button; I2C Bus 100nF GND GND; GND; GND MPU-9250 +3V³; MAX44009; 1uF GND ¹⁰k; 100nF GND ¹⁰k +3V³; 100nF GND ⁺³V³ ADXL327 ¹⁰⁰nF GND ⁺³V³; 100nF GND ⁺³V³; 100nF GND; AUX_DA 21; AUX_CL 7; VDDIO ¹*2 VDD ¹³; AD0/MISO; 9 SDA/MOSI; 24 SCLK; 22 INT; 12 REGOUT 10; FSYNC 11; GND 18*2 U3; VCC; 1 GND; 3 INT 4; SCL 5; SDA 6; C¹⁰ R⁵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

## SD Card Adapter

# 4 GND


### Top and Bottom Layers


### Top Layer


### Bottom Layer


### Top Copper Layer


### Bottom Copper Layer


### Top Paste Layer with Silkscreen



### Bottom Paste Layer with Silkscreen

### Top and Bottom Layers 1:1 Scale


### Top Layer 1:1 Scale


### Bottom Copper Layer 1:1 Scale


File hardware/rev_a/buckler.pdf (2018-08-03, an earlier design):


2 3-Axis Accelerometer/Gyro/Magnetometer I2C Address: 0x68; Humidity Pressure Ambient Light Analog Accelerometer; I2C Address: 0x4A I2C Address: 0x76 I2C Address: 0x40 Self Test Button; I2C Bus 100nF GND GND; GND; GND MPU-9250 +3V³; MAX44009; 1uF GND ¹⁰k; 100nF GND ¹⁰k +3V³; 100nF GND ⁺³V³ ADXL327 ¹⁰⁰nF GND ⁺³V³; 100nF GND ⁺³V³; 100nF GND; AUX_DA 21; AUX_CL 7; VDDIO ¹*2 VDD ¹³; AD0/MISO; 9 SDA/MOSI; 24 SCLK; 22 INT; 12 REGOUT 10; FSYNC 11; GND 18*2 U3; VCC; 1 GND; 3 INT 4; SCL 5; SDA 6; C¹⁰ R⁵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

## SD Card Adapter

# 4 GND


### Top and Bottom Layers


### Top Layer


### Bottom Layer


### Top Copper Layer


### Bottom Copper Layer


### Top Paste Layer with Silkscreen



### Bottom Paste Layer with Silkscreen

### Top and Bottom Layers 1:1 Scale


### Top Layer 1:1 Scale


### Bottom Copper Layer 1:1 Scale


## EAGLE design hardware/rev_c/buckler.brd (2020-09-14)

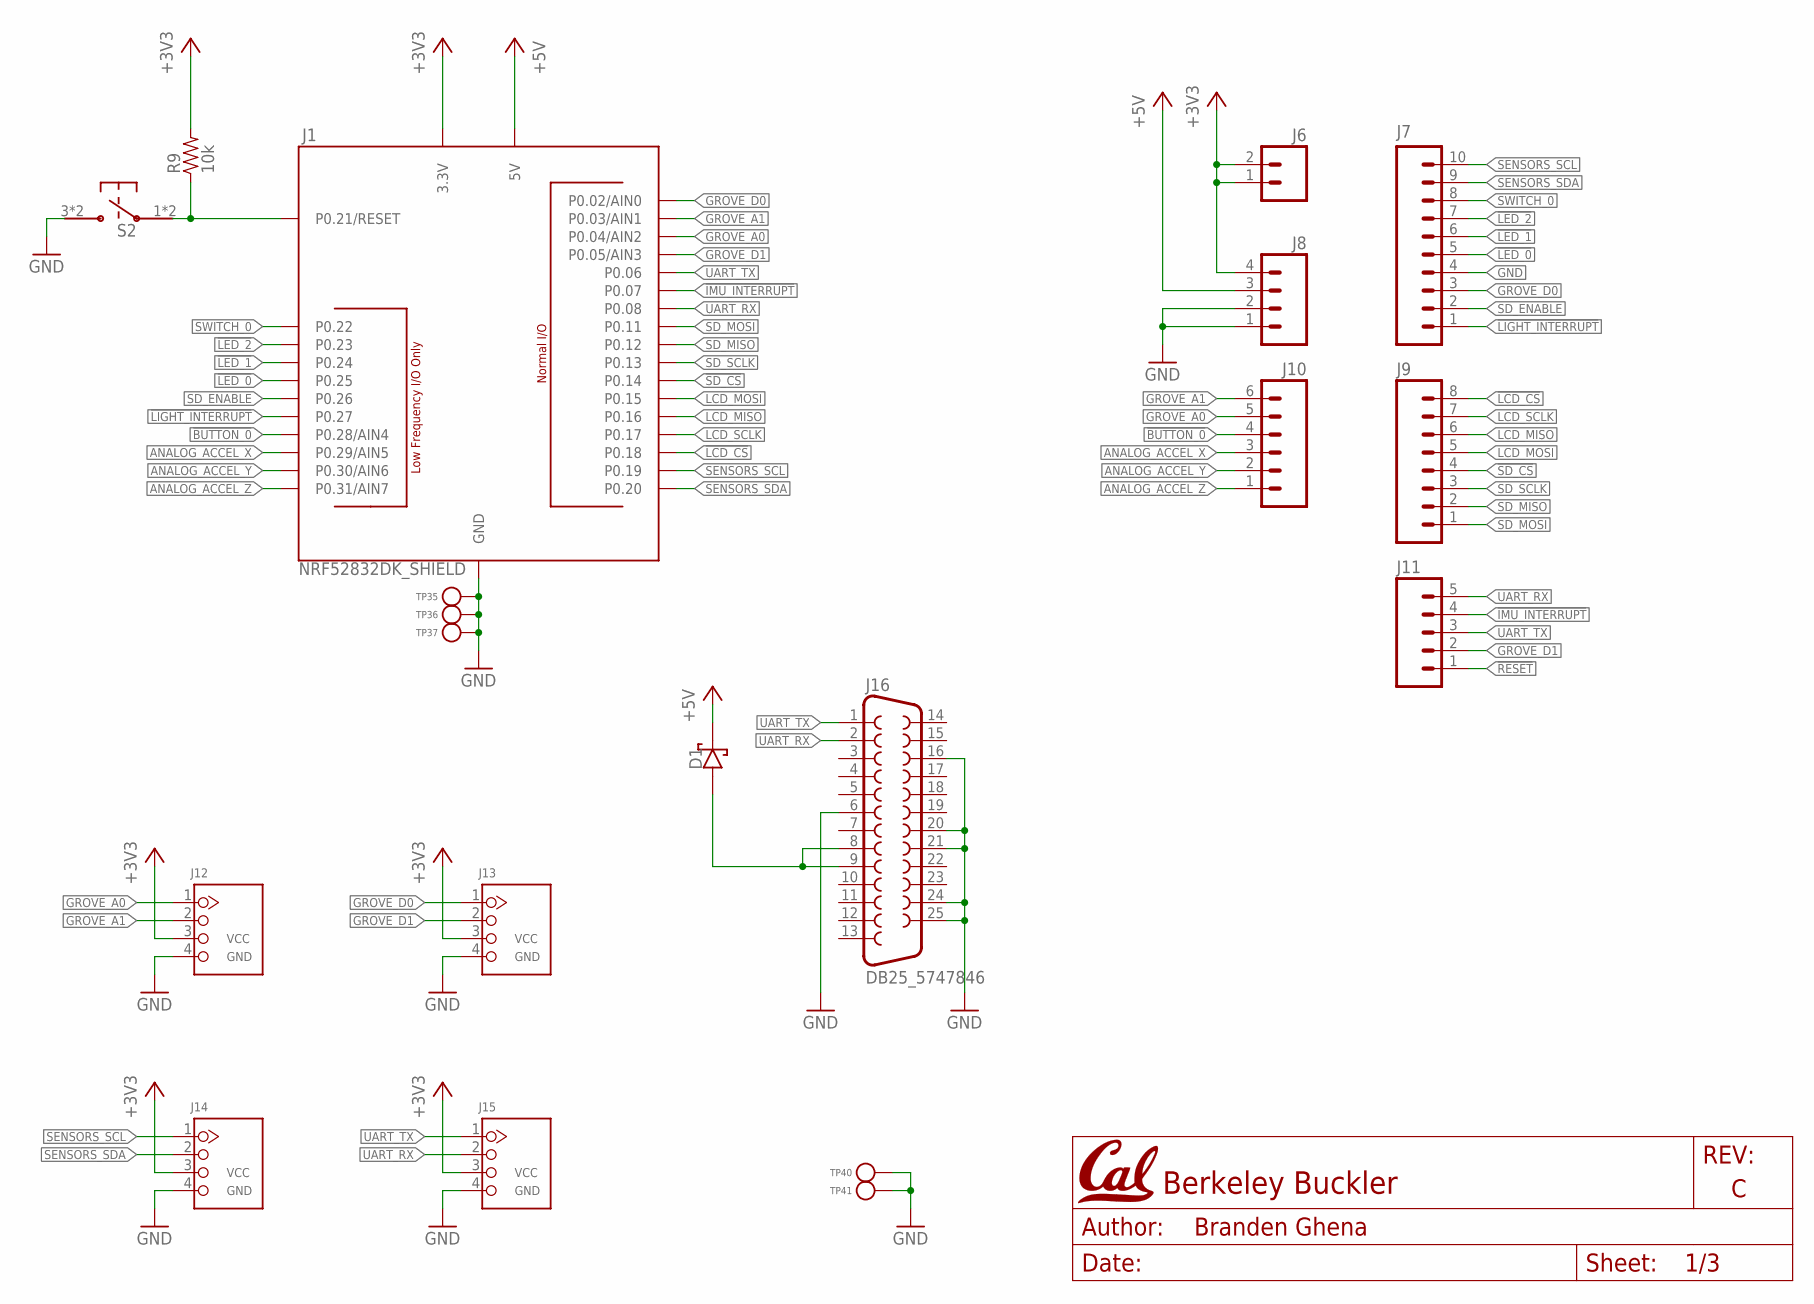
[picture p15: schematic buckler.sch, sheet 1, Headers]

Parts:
D1: DIODE_SCHOTTKYSOD323; SOD323; MPN B0530WS-7-F; DIGIKEY B0530WS-FDICT-ND
J1: NRF52832DK_SHIELD; DIGIKEY1 S1011EC-10-ND
J6: M02PTH; 1X02; DIGIKEY S1011EC-02-ND
J7: M10"; 1X10; DIGIKEY S1011EC-10-ND
J8: M04PTH; 1X04; DIGIKEY S1011EC-04-ND
J9: M081X08; 1X08; DIGIKEY S1011EC-08-ND
J10: M06SIP; 1X06; DIGIKEY S1011EC-06-ND
J11: M05PTH; 1X05; DIGIKEY S1011EC-05-ND
J12, J13, J14, J15: GROVE-CONNECTOR-DIP(4P-2.0); HW4-2.0; MPN 110990030; MOUSER 713-110990030
J16: DB25_5747846; MPN 5747846-4
R9: 10k; 0402_RES; MPN RC1005F103CS; DIGIKEY 1276-3431-1-ND
S2: PTS645SM43SMTR92; PTS645; MPN PTS645SM43SMTR92 LFS
TP35, TP36, TP37: TEST_POINT_0.040IN; TESTPOINT_0.040IN
TP40, TP41: TEST_POINT_0.078IN; TESTPOINT_0.078IN; MPN 1520-2; DIGIKEY 36-1520-2-ND

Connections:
5V_IN: D1.P$2 (ANODE), J16.8, J16.9
!BUTTON_0: J1.P0.28 (P0.28/AIN4), J10.4; also elsewhere on the board
!IMU_INTERRUPT: J1.P0.07, J11.4; also elsewhere on the board
!LCD_CS: J1.P0.18, J9.8; also elsewhere on the board
!LED_0: J1.P0.25, J7.5; also elsewhere on the board
!LED_1: J1.P0.24, J7.6; also elsewhere on the board
!LED_2: J1.P0.23, J7.7; also elsewhere on the board
!LIGHT_INTERRUPT: J1.P0.27, J7.1; also elsewhere on the board
!RESET: J1.P0.21 (P0.21/RESET), J11.1, R9.1, S2.1, S2.2
!SD_CS: J1.P0.14, J9.4; also elsewhere on the board
+3V3: J1.3.3V@0 (3.3V), J1.3.3V@1 (3.3V), J1.3.3V@2 (3.3V), J6.1, J6.2, J8.4, J12.3, J13.3, J14.3, J15.3, R9.2; also elsewhere on the board
+5V: D1.P$1 (CATHODE), J1.5V, J8.3
ANALOG_ACCEL_X: J1.P0.29 (P0.29/AIN5), J10.3; also elsewhere on the board
ANALOG_ACCEL_Y: J1.P0.30 (P0.30/AIN6), J10.2; also elsewhere on the board
ANALOG_ACCEL_Z: J1.P0.31 (P0.31/AIN7), J10.1; also elsewhere on the board
GND: J1.GND@0 (GND), J1.GND@1 (GND), J1.GND@2 (GND), J7.4, J8.1, J8.2, J12.4, J13.4, J14.4, J15.4, J16.6, J16.16, J16.20, J16.21, J16.24, J16.25, S2.3, S2.4, TP35.TESTPOINT, TP36.TESTPOINT, TP37.TESTPOINT, TP40.1, TP41.1; also elsewhere on the board
GROVE_A0: J1.P0.04 (P0.04/AIN2), J10.5, J12.1
GROVE_A1: J1.P0.03 (P0.03/AIN1), J10.6, J12.2
GROVE_D0: J1.P0.02 (P0.02/AIN0), J7.3, J13.1
GROVE_D1: J1.P0.05 (P0.05/AIN3), J11.2, J13.2
LCD_MISO: J1.P0.16, J9.6; also elsewhere on the board
LCD_MOSI: J1.P0.15, J9.5; also elsewhere on the board
LCD_SCLK: J1.P0.17, J9.7; also elsewhere on the board
SD_ENABLE: J1.P0.26, J7.2; also elsewhere on the board
SD_MISO: J1.P0.12, J9.2; also elsewhere on the board
SD_MOSI: J1.P0.11, J9.1; also elsewhere on the board
SD_SCLK: J1.P0.13, J9.3; also elsewhere on the board
SENSORS_SCL: J1.P0.19, J7.10, J14.1; also elsewhere on the board
SENSORS_SDA: J1.P0.20, J7.9, J14.2; also elsewhere on the board
SWITCH_0: J1.P0.22, J7.8; also elsewhere on the board
UART_RX: J1.P0.08, J11.5, J15.2, J16.2
UART_TX: J1.P0.06, J11.3, J15.1, J16.1

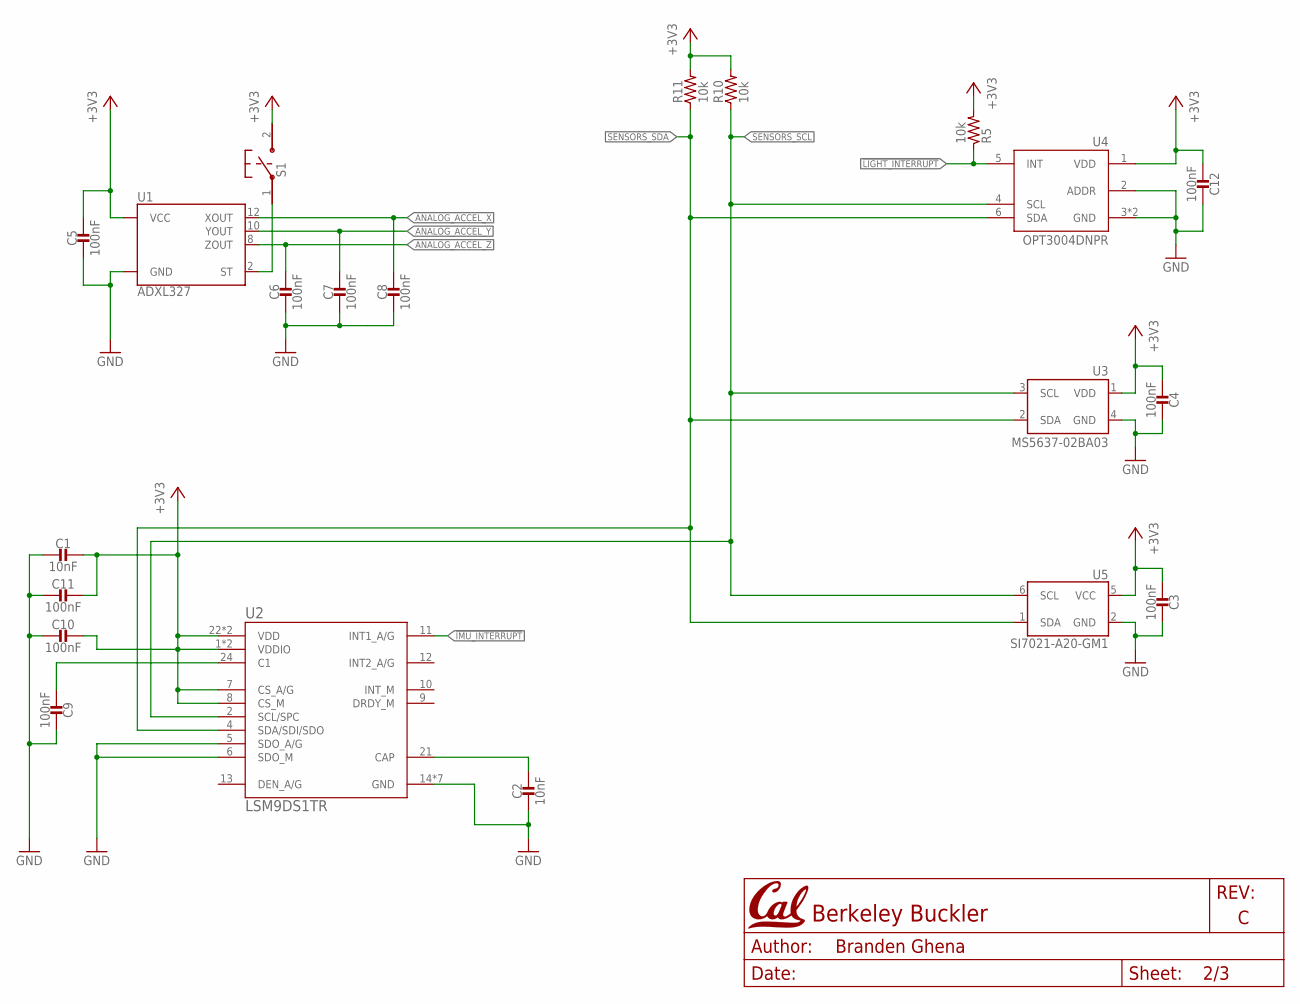
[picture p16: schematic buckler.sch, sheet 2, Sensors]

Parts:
C1, C2: 10nF; 0402_CAP; MPN C0402C103J3RACTU; DIGIKEY 399-1279-1-ND
C3, C4, C5, C6, C7, C8, C9, C10, C11, C12: 100nF; 0402_CAP; MPN GCM155R71C104KA55D; DIGIKEY 490-4759-1-ND
R5, R10, R11: 10k; 0402_RES; MPN RC1005F103CS; DIGIKEY 1276-3431-1-ND
S1: B3U-1000P; MPN B3U-1000P
U1: ADXL327; LFCSP-16; MPN ADXL327BCPZ
U2: LSM9DS1TR; LGA-24_3X3P5X1_STM
U3: MS5637-02BA03; 4-SMD
U4: OPT3004DNPR; DNP0006A
U5: SI7021-A20-GM1; DFN-6/3MM; MPN SI7021-A20-GM1

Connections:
!IMU_INTERRUPT: U2.11 (INT1_A/G); also elsewhere on the board
!LIGHT_INTERRUPT: R5.1, U4.5 (INT); also elsewhere on the board
+3V3: C1.2, C3.1, C4.1, C5.1, C10.2, C11.2, C12.1, R5.2, R10.2, R11.2, S1.2, U1.14 (VCC), U1.15 (VCC), U2.1 (VDDIO), U2.3 (VDDIO), U2.7 (CS_A/G), U2.8 (CS_M), U2.22 (VDD), U2.23 (VDD), U3.1 (VDD), U4.1 (VDD), U5.5 (VCC); also elsewhere on the board
ANALOG_ACCEL_X: C8.1, U1.12 (XOUT); also elsewhere on the board
ANALOG_ACCEL_Y: C7.1, U1.10 (YOUT); also elsewhere on the board
ANALOG_ACCEL_Z: C6.1, U1.8 (ZOUT); also elsewhere on the board
GND: C1.1, C2.1, C3.2, C4.2, C5.2, C6.2, C7.2, C8.2, C9.2, C10.1, C11.1, C12.2, U1.3 (GND), U1.5 (GND), U1.6 (GND), U1.7 (GND), U2.5 (SDO_A/G), U2.6 (SDO_M), U2.14 (GND), U2.15 (GND), U2.16 (GND), U2.17 (GND), U2.18 (GND), U2.19 (GND), U2.20 (GND), U3.4 (GND), U4.2 (ADDR), U4.3 (GND), U4.7 (GND), U5.2 (GND); also elsewhere on the board
unnamed: C9.1, U2.24 (C1)
unnamed: C2.2, U2.21 (CAP)
unnamed: S1.1, U1.2 (ST)
SENSORS_SCL: R10.1, U2.2 (SCL/SPC), U3.3 (SCL), U4.4 (SCL), U5.6 (SCL); also elsewhere on the board
SENSORS_SDA: R11.1, U2.4 (SDA/SDI/SDO), U3.2 (SDA), U4.6 (SDA), U5.1 (SDA); also elsewhere on the board

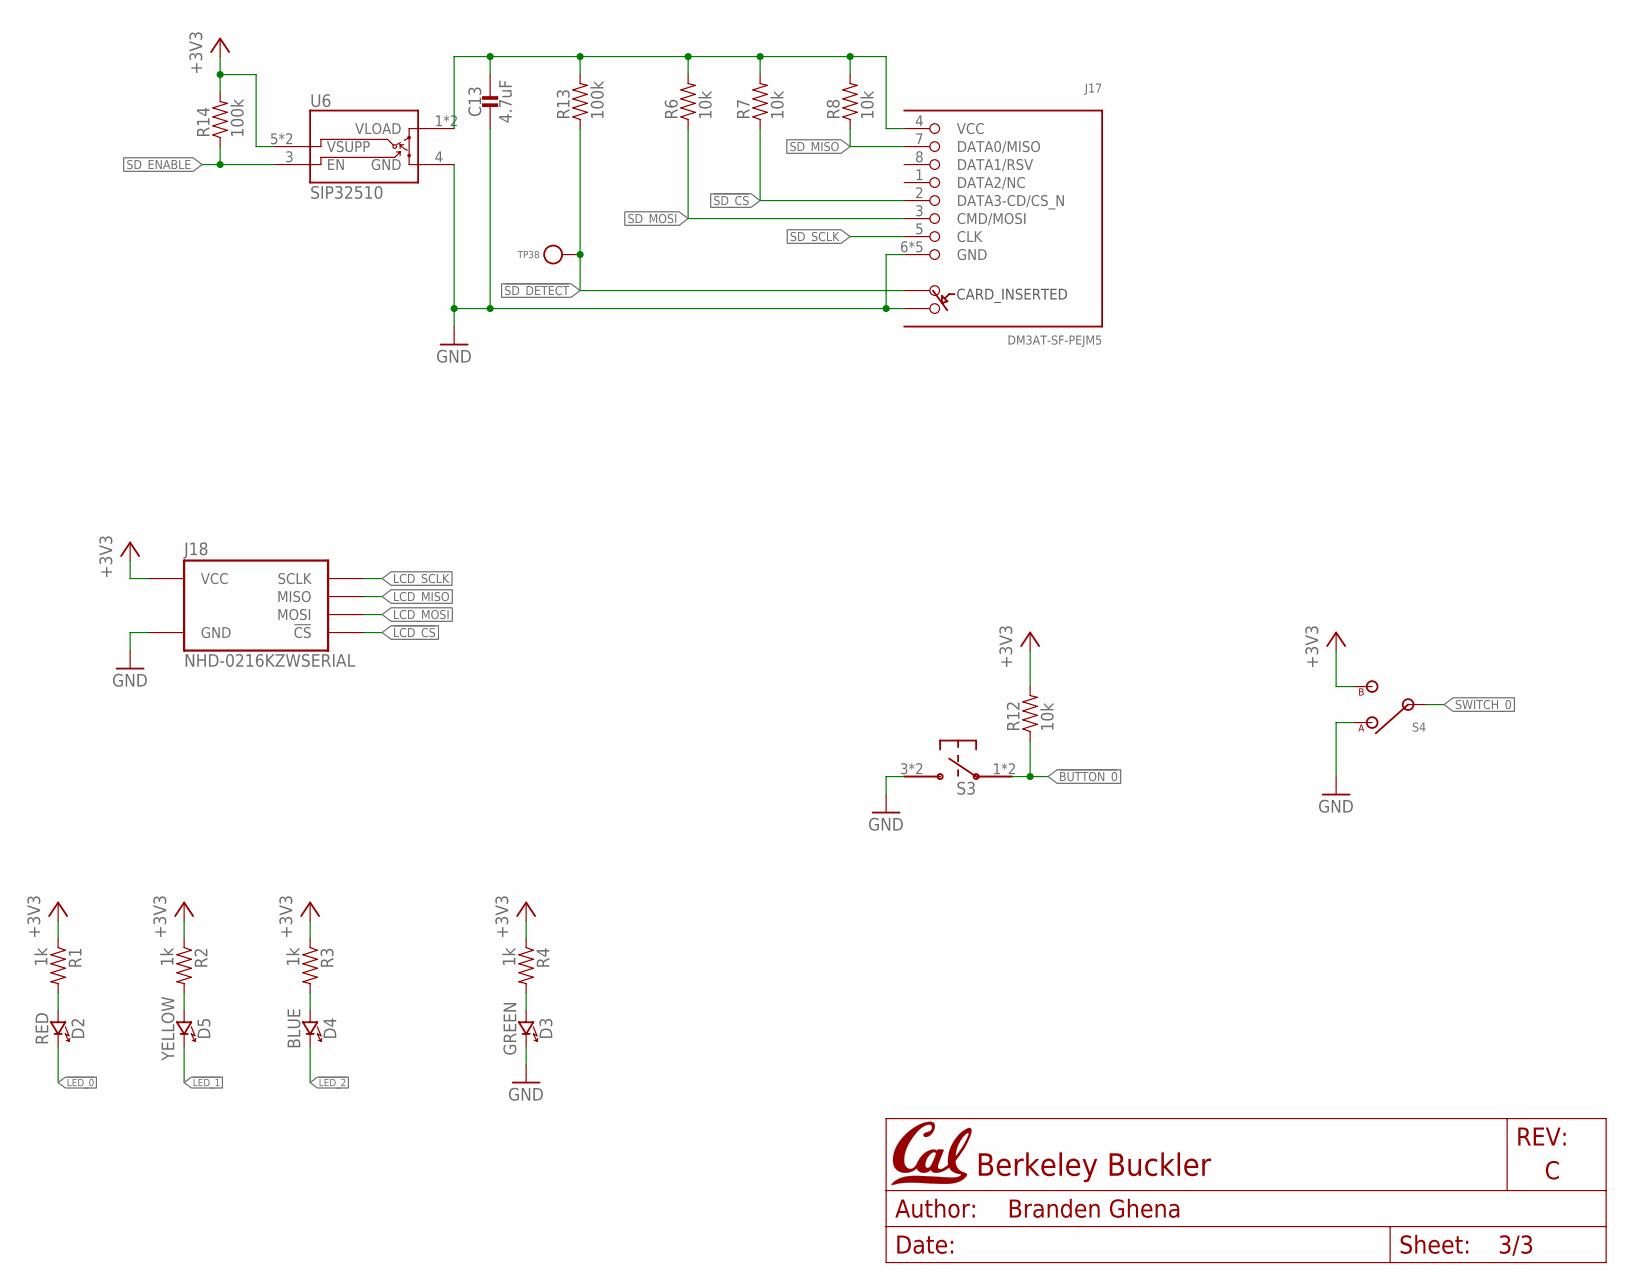
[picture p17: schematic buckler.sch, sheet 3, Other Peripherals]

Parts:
C13: 4.7uF; 0402_CAP; MPN CL05A475KP5NRNC; DIGIKEY 1276-1480-1-ND
D2: RED; LED-0603; MPN LTST-C190KRKT; DIGIKEY 160-1436-1-ND
D3: GREEN; LED-0603; MPN LTST-C190KGKT; DIGIKEY 160-1435-1-ND
D4: BLUE; LED-0603; MPN LTST-C194TBKT; DIGIKEY 160-1837-1-ND
D5: YELLOW; LED-0603; MPN LTST-C190KSKT; DIGIKEY 160-1437-1-ND
J17: DM3AT-SF-PEJM5
J18: NHD-0216KZWSERIAL; NHD-0216KZW; DIGIKEY1 NHD-0216KZW-AG5-ND
R1, R2, R3, R4: 1k; 0402_RES; MPN RMCF0402FT1K00; DIGIKEY RMCF0402FT1K00CT-ND
R6, R7, R8, R12: 10k; 0402_RES; MPN RC1005F103CS; DIGIKEY 1276-3431-1-ND
R13, R14: 100k; 0402_RES; MPN CRCW0402100KFKEDHP; DIGIKEY 541-100KYCT-ND
S3: PTS645SM43SMTR92; PTS645; MPN PTS645SM43SMTR92 LFS
S4: TE_SSA12/SPDT; MPN SSA12
TP38: TEST_POINT_0.040IN; TESTPOINT_0.040IN
U6: SIP32510; TSOT23-6

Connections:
!BUTTON_0: R12.1, S3.1, S3.2; also elsewhere on the board
!LCD_CS: J18.16 (!CS); also elsewhere on the board
!LED_0: D2.C (CATHODE); also elsewhere on the board
!LED_1: D5.C (CATHODE); also elsewhere on the board
!LED_2: D4.C (CATHODE); also elsewhere on the board
!SD_CS: J17.2 (DATA3-CD/CS_N), R7.1; also elsewhere on the board
!SD_DETECT: J17.A, R13.1, TP38.TESTPOINT
+3V3: J18.2 (VCC), R1.1, R2.1, R3.1, R4.1, R12.2, R14.2, S4.2 (B), U6.5 (VSUPP), U6.6 (VSUPP); also elsewhere on the board
GND: C13.2, D3.C (CATHODE), J17.6 (GND), J17.B, J17.MOUNT0 (GND), J17.MOUNT1 (GND), J17.MOUNT2 (GND), J17.MOUNT3 (GND), J18.1 (GND), S3.3, S3.4, S4.1 (A), U6.4 (GND); also elsewhere on the board
LCD_MISO: J18.13 (MISO); also elsewhere on the board
LCD_MOSI: J18.14 (MOSI); also elsewhere on the board
LCD_SCLK: J18.12 (SCLK); also elsewhere on the board
unnamed: D3.A (ANODE), R4.2
unnamed: D4.A (ANODE), R3.2
unnamed: D5.A (ANODE), R2.2
unnamed: C13.1, J17.4 (VCC), R6.2, R7.2, R8.2, R13.2, U6.1 (VLOAD), U6.2 (VLOAD)
unnamed: D2.A (ANODE), R1.2
SD_ENABLE: R14.1, U6.3 (EN); also elsewhere on the board
SD_MISO: J17.7 (DATA0/MISO), R8.1; also elsewhere on the board
SD_MOSI: J17.3 (CMD/MOSI), R6.1; also elsewhere on the board
SD_SCLK: J17.5 (CLK); also elsewhere on the board
SWITCH_0: S4.IN; also elsewhere on the board

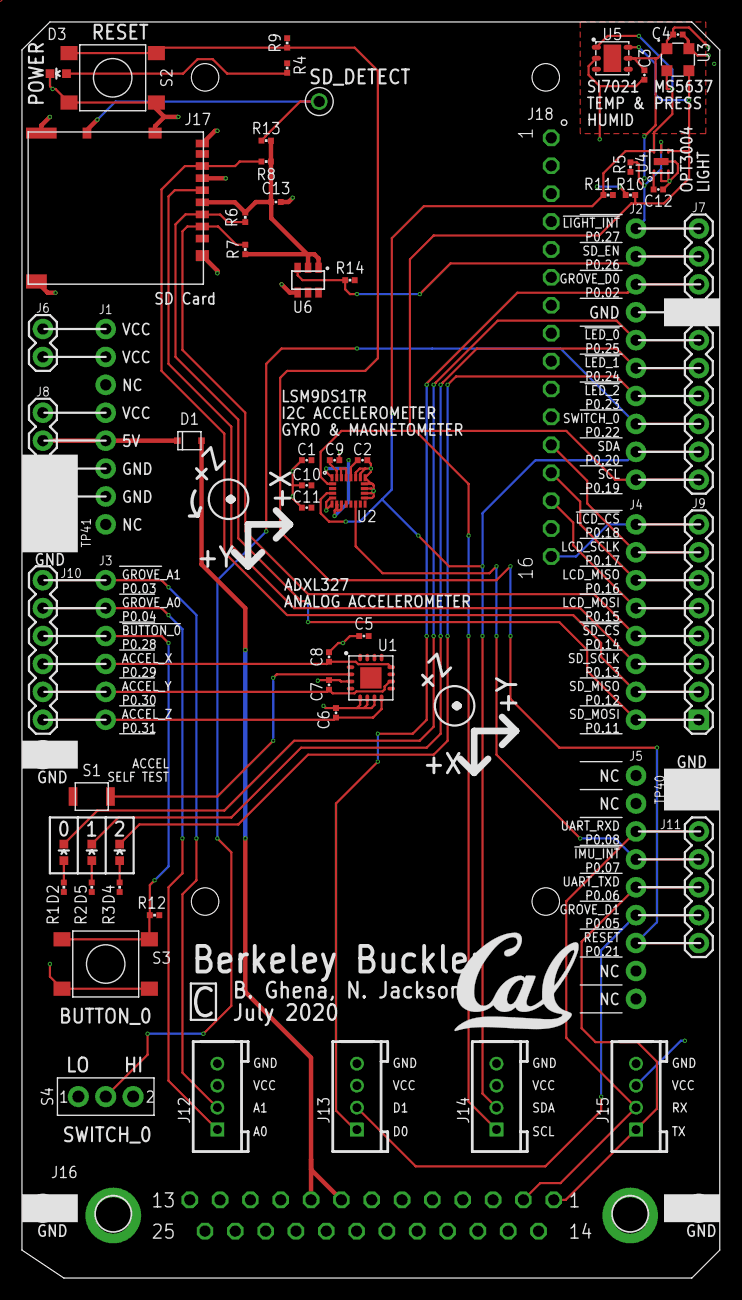
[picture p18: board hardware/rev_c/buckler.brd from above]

Board: 2 copper layers, 63.5 x 114.3 mm, 63 parts (0 on the bottom side), 41 nets.

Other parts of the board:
U$5: UCB_CAL_350MIL

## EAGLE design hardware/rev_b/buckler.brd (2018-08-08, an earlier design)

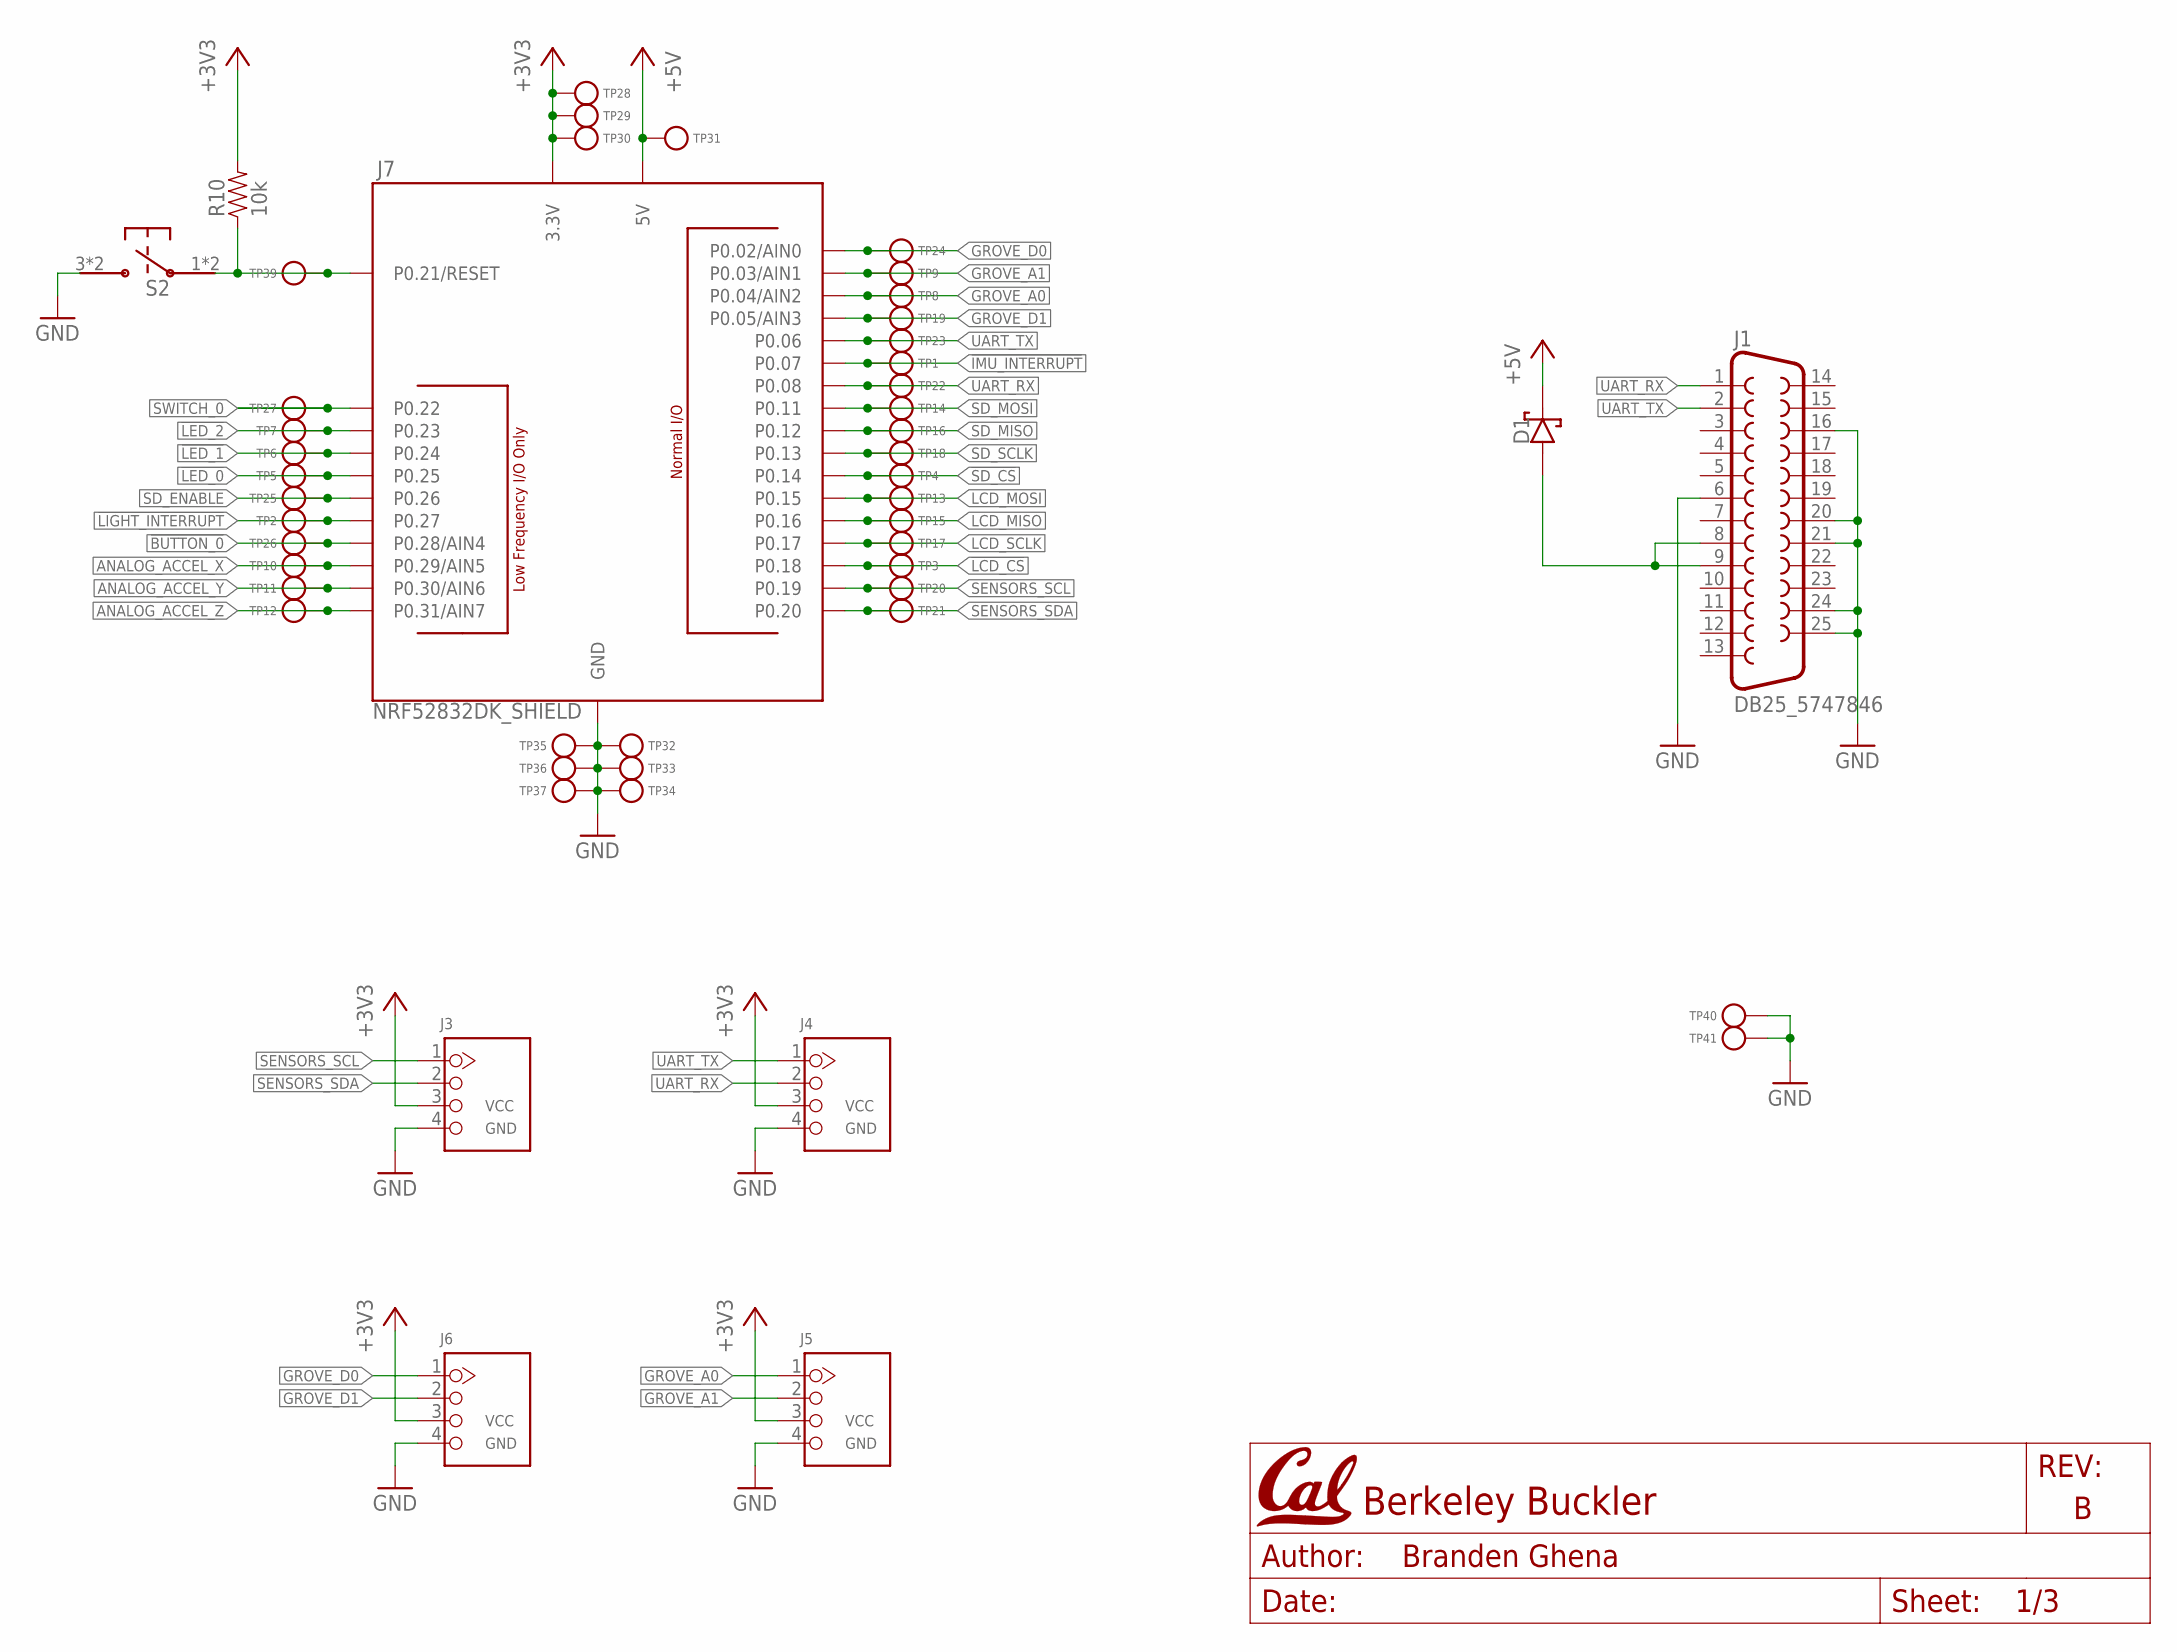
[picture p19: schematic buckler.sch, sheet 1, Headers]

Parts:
D1: DIODE_SCHOTTKYSOD323; SOD323; MPN B0530WS-7-F; DIGIKEY B0530WS-FDICT-ND
J1: DB25_5747846; MPN 5747846-4
J3, J4, J5, J6: GROVE-CONNECTOR-DIP(4P-2.0); HW4-2.0; MPN 110990030; MOUSER 713-110990030
J7: NRF52832DK_SHIELD; DIGIKEY1 S1011EC-10-ND
R10: 10k; 0402_RES; MPN RC1005F103CS; DIGIKEY 1276-3431-1-ND
S2: PTS645SM43SMTR92; PTS645; MPN PTS645SM43SMTR92 LFS
TP1, TP2, TP3, TP4, TP5, TP6, TP7, TP8, TP9, TP10, TP11, TP12, TP13, TP14, TP15, TP16, TP17, TP18, TP19, TP20, TP21, TP22, TP23, TP24, TP25, TP26, TP27, TP28, TP29, TP30, TP31, TP32, TP33, TP34, TP35, TP36, TP37, TP39: TEST_POINT_0.040IN; TESTPOINT_0.040IN
TP40, TP41: TEST_POINT_0.078IN; TESTPOINT_0.078IN; MPN 1520-2; DIGIKEY 36-1520-2-ND

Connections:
5V_IN: D1.P$2 (ANODE), J1.8, J1.9
!BUTTON_0: J7.P0.28 (P0.28/AIN4), TP26.TESTPOINT; also elsewhere on the board
!IMU_INTERRUPT: J7.P0.07, TP1.TESTPOINT; also elsewhere on the board
!LCD_CS: J7.P0.18, TP3.TESTPOINT; also elsewhere on the board
!LED_0: J7.P0.25, TP5.TESTPOINT; also elsewhere on the board
!LED_1: J7.P0.24, TP6.TESTPOINT; also elsewhere on the board
!LED_2: J7.P0.23, TP7.TESTPOINT; also elsewhere on the board
!LIGHT_INTERRUPT: J7.P0.27, TP2.TESTPOINT; also elsewhere on the board
!RESET: J7.P0.21 (P0.21/RESET), R10.1, S2.1, S2.2, TP39.TESTPOINT
!SD_CS: J7.P0.14, TP4.TESTPOINT; also elsewhere on the board
+3V3: J3.3, J4.3, J5.3, J6.3, J7.3.3V@0 (3.3V), J7.3.3V@1 (3.3V), J7.3.3V@2 (3.3V), R10.2, TP28.TESTPOINT, TP29.TESTPOINT, TP30.TESTPOINT; also elsewhere on the board
+5V: D1.P$1 (CATHODE), J7.5V, TP31.TESTPOINT
ANALOG_ACCEL_X: J7.P0.29 (P0.29/AIN5), TP10.TESTPOINT; also elsewhere on the board
ANALOG_ACCEL_Y: J7.P0.30 (P0.30/AIN6), TP11.TESTPOINT; also elsewhere on the board
ANALOG_ACCEL_Z: J7.P0.31 (P0.31/AIN7), TP12.TESTPOINT; also elsewhere on the board
GND: J1.6, J1.16, J1.20, J1.21, J1.24, J1.25, J3.4, J4.4, J5.4, J6.4, J7.GND@0 (GND), J7.GND@1 (GND), J7.GND@2 (GND), S2.3, S2.4, TP32.TESTPOINT, TP33.TESTPOINT, TP34.TESTPOINT, TP35.TESTPOINT, TP36.TESTPOINT, TP37.TESTPOINT, TP40.1, TP41.1; also elsewhere on the board
GROVE_A0: J5.1, J7.P0.04 (P0.04/AIN2), TP8.TESTPOINT
GROVE_A1: J5.2, J7.P0.03 (P0.03/AIN1), TP9.TESTPOINT
GROVE_D0: J6.1, J7.P0.02 (P0.02/AIN0), TP24.TESTPOINT
GROVE_D1: J6.2, J7.P0.05 (P0.05/AIN3), TP19.TESTPOINT
LCD_MISO: J7.P0.16, TP15.TESTPOINT; also elsewhere on the board
LCD_MOSI: J7.P0.15, TP13.TESTPOINT; also elsewhere on the board
LCD_SCLK: J7.P0.17, TP17.TESTPOINT; also elsewhere on the board
SD_ENABLE: J7.P0.26, TP25.TESTPOINT; also elsewhere on the board
SD_MISO: J7.P0.12, TP16.TESTPOINT; also elsewhere on the board
SD_MOSI: J7.P0.11, TP14.TESTPOINT; also elsewhere on the board
SD_SCLK: J7.P0.13, TP18.TESTPOINT; also elsewhere on the board
SENSORS_SCL: J3.1, J7.P0.19, TP20.TESTPOINT; also elsewhere on the board
SENSORS_SDA: J3.2, J7.P0.20, TP21.TESTPOINT; also elsewhere on the board
SWITCH_0: J7.P0.22, TP27.TESTPOINT; also elsewhere on the board
UART_RX: J1.1, J4.2, J7.P0.08, TP22.TESTPOINT
UART_TX: J1.2, J4.1, J7.P0.06, TP23.TESTPOINT

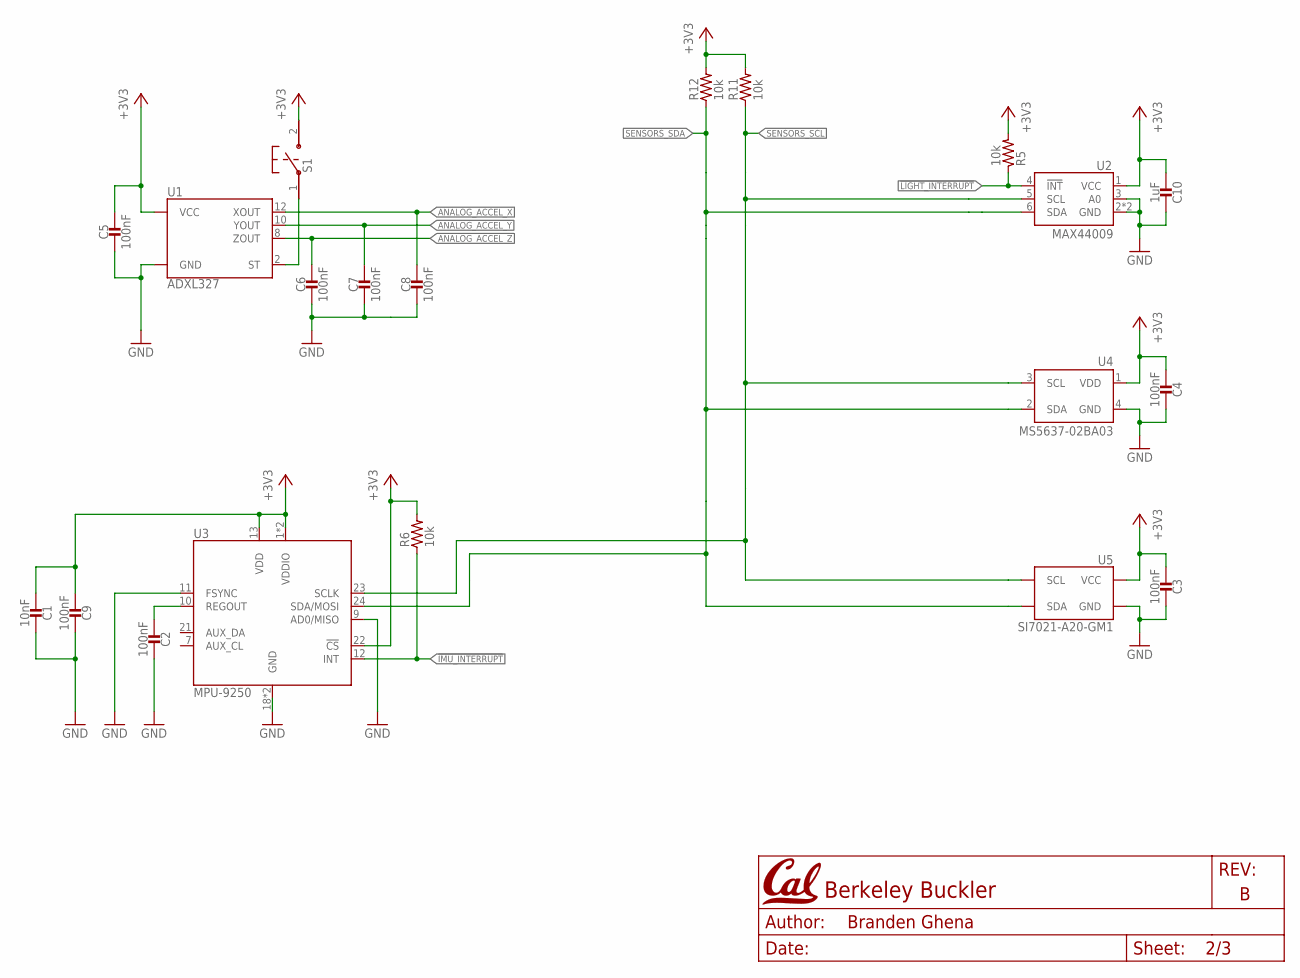
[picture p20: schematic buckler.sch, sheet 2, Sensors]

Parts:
C1: 10nF; 0402_CAP; MPN C0402C103J3RACTU; DIGIKEY 399-1279-1-ND
C2, C3, C4, C5, C6, C7, C8, C9: 100nF; 0402_CAP; MPN GCM155R71C104KA55D; DIGIKEY 490-4759-1-ND
C10: 1uF; 0402_CAP; MPN CL05X105KP5NNNC; DIGIKEY 1276-6805-1-ND
R5, R6, R11, R12: 10k; 0402_RES; MPN RC1005F103CS; DIGIKEY 1276-3431-1-ND
S1: B3U-1000P; MPN B3U-1000P
U1: ADXL327; LFCSP-16; MPN ADXL327BCPZ
U2: MAX44009; UDFN-6-EXPOSED
U3: MPU-9250; QFN-24/3MM; MPN MPU-9250
U4: MS5637-02BA03; 4-SMD
U5: SI7021-A20-GM1; DFN-6/3MM; MPN SI7021-A20-GM1

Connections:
!IMU_INTERRUPT: R6.1, U3.12 (INT); also elsewhere on the board
!LIGHT_INTERRUPT: R5.1, U2.4 (!INT); also elsewhere on the board
+3V3: C1.1, C3.1, C4.1, C5.1, C9.1, C10.1, R5.2, R6.2, R11.2, R12.2, S1.2, U1.14 (VCC), U1.15 (VCC), U2.1 (VCC), U3.1 (VDDIO), U3.8 (VDDIO), U3.13 (VDD), U3.22 (!CS), U4.1 (VDD), U5.5 (VCC); also elsewhere on the board
ANALOG_ACCEL_X: C8.1, U1.12 (XOUT); also elsewhere on the board
ANALOG_ACCEL_Y: C7.1, U1.10 (YOUT); also elsewhere on the board
ANALOG_ACCEL_Z: C6.1, U1.8 (ZOUT); also elsewhere on the board
GND: C1.2, C2.2, C3.2, C4.2, C5.2, C6.2, C7.2, C8.2, C9.2, C10.2, U1.3 (GND), U1.5 (GND), U1.6 (GND), U1.7 (GND), U2.2 (GND), U2.3 (A0), U2.EP (GND), U3.9 (AD0/MISO), U3.11 (FSYNC), U3.18 (GND), U3.20 (GND), U4.4 (GND), U5.2 (GND); also elsewhere on the board
unnamed: S1.1, U1.2 (ST)
unnamed: C2.1, U3.10 (REGOUT)
SENSORS_SCL: R11.1, U2.5 (SCL), U3.23 (SCLK), U4.3 (SCL), U5.6 (SCL); also elsewhere on the board
SENSORS_SDA: R12.1, U2.6 (SDA), U3.24 (SDA/MOSI), U4.2 (SDA), U5.1 (SDA); also elsewhere on the board

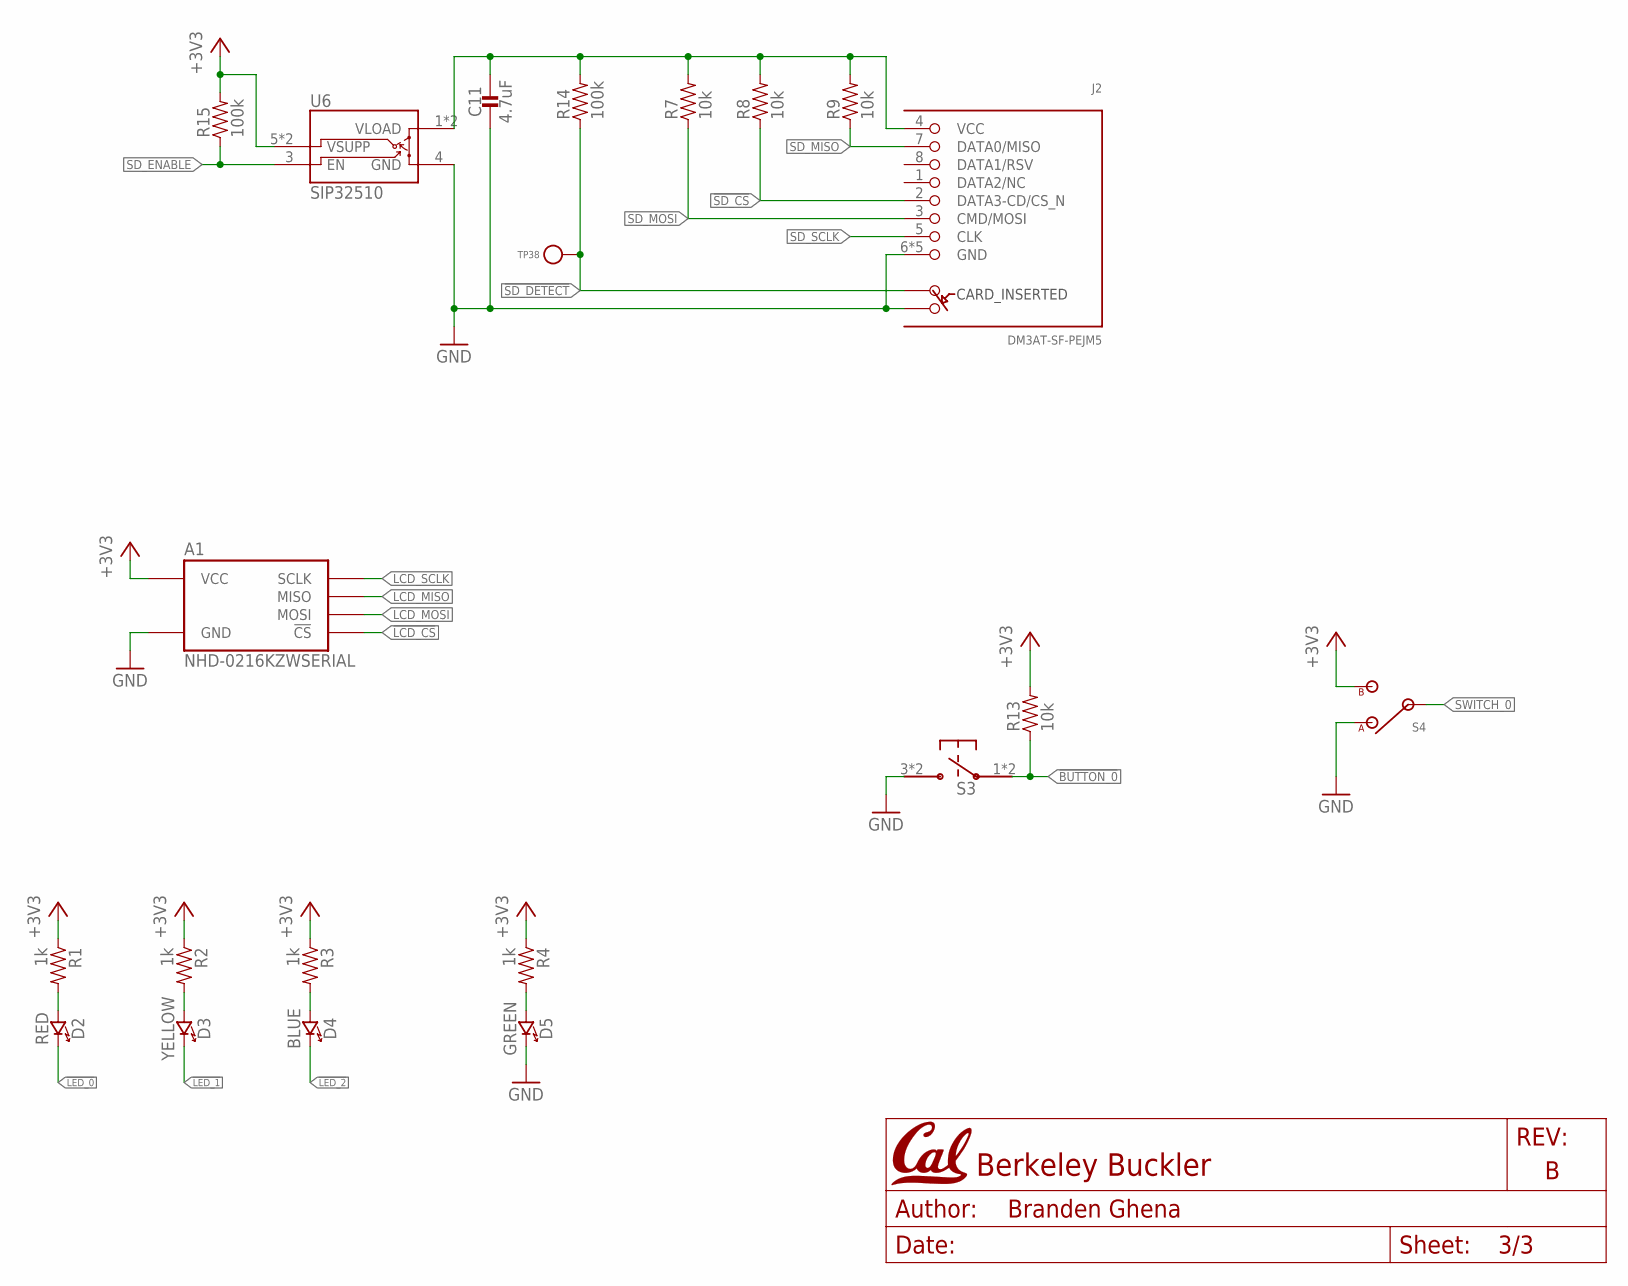
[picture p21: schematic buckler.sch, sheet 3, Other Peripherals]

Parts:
A1: NHD-0216KZWSERIAL; NHD-0216KZW; DIGIKEY1 NHD-0216KZW-AG5-ND
C11: 4.7uF; 0402_CAP; MPN CL05A475KP5NRNC; DIGIKEY 1276-1480-1-ND
D2: RED; LED-0603; MPN LTST-C190KRKT; DIGIKEY 160-1436-1-ND
D3: YELLOW; LED-0603; MPN LTST-C190KSKT; DIGIKEY 160-1437-1-ND
D4: BLUE; LED-0603; MPN LTST-C194TBKT; DIGIKEY 160-1837-1-ND
D5: GREEN; LED-0603; MPN LTST-C190KGKT; DIGIKEY 160-1435-1-ND
J2: DM3AT-SF-PEJM5
R1, R2, R3, R4: 1k; 0402_RES; MPN RMCF0402FT1K00; DIGIKEY RMCF0402FT1K00CT-ND
R7, R8, R9, R13: 10k; 0402_RES; MPN RC1005F103CS; DIGIKEY 1276-3431-1-ND
R14, R15: 100k; 0402_RES; MPN CRCW0402100KFKEDHP; DIGIKEY 541-100KYCT-ND
S3: PTS645SM43SMTR92; PTS645; MPN PTS645SM43SMTR92 LFS
S4: TE_SSA12/SPDT; MPN SSA12
TP38: TEST_POINT_0.040IN; TESTPOINT_0.040IN
U6: SIP32510; TSOT23-6

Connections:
!BUTTON_0: R13.1, S3.1, S3.2; also elsewhere on the board
!LCD_CS: A1.16 (!CS); also elsewhere on the board
!LED_0: D2.C (CATHODE); also elsewhere on the board
!LED_1: D3.C (CATHODE); also elsewhere on the board
!LED_2: D4.C (CATHODE); also elsewhere on the board
!SD_CS: J2.2 (DATA3-CD/CS_N), R8.1; also elsewhere on the board
!SD_DETECT: J2.A, R14.1, TP38.TESTPOINT
+3V3: A1.2 (VCC), R1.1, R2.1, R3.1, R4.1, R13.2, R15.2, S4.2 (B), U6.5 (VSUPP), U6.6 (VSUPP); also elsewhere on the board
GND: A1.1 (GND), C11.2, D5.C (CATHODE), J2.6 (GND), J2.B, J2.MOUNT0 (GND), J2.MOUNT1 (GND), J2.MOUNT2 (GND), J2.MOUNT3 (GND), S3.3, S3.4, S4.1 (A), U6.4 (GND); also elsewhere on the board
LCD_MISO: A1.13 (MISO); also elsewhere on the board
LCD_MOSI: A1.14 (MOSI); also elsewhere on the board
LCD_SCLK: A1.12 (SCLK); also elsewhere on the board
unnamed: D5.A (ANODE), R4.2
unnamed: D4.A (ANODE), R3.2
unnamed: D3.A (ANODE), R2.2
unnamed: C11.1, J2.4 (VCC), R7.2, R8.2, R9.2, R14.2, U6.1 (VLOAD), U6.2 (VLOAD)
unnamed: D2.A (ANODE), R1.2
SD_ENABLE: R15.1, U6.3 (EN); also elsewhere on the board
SD_MISO: J2.7 (DATA0/MISO), R9.1; also elsewhere on the board
SD_MOSI: J2.3 (CMD/MOSI), R7.1; also elsewhere on the board
SD_SCLK: J2.5 (CLK); also elsewhere on the board
SWITCH_0: S4.IN; also elsewhere on the board

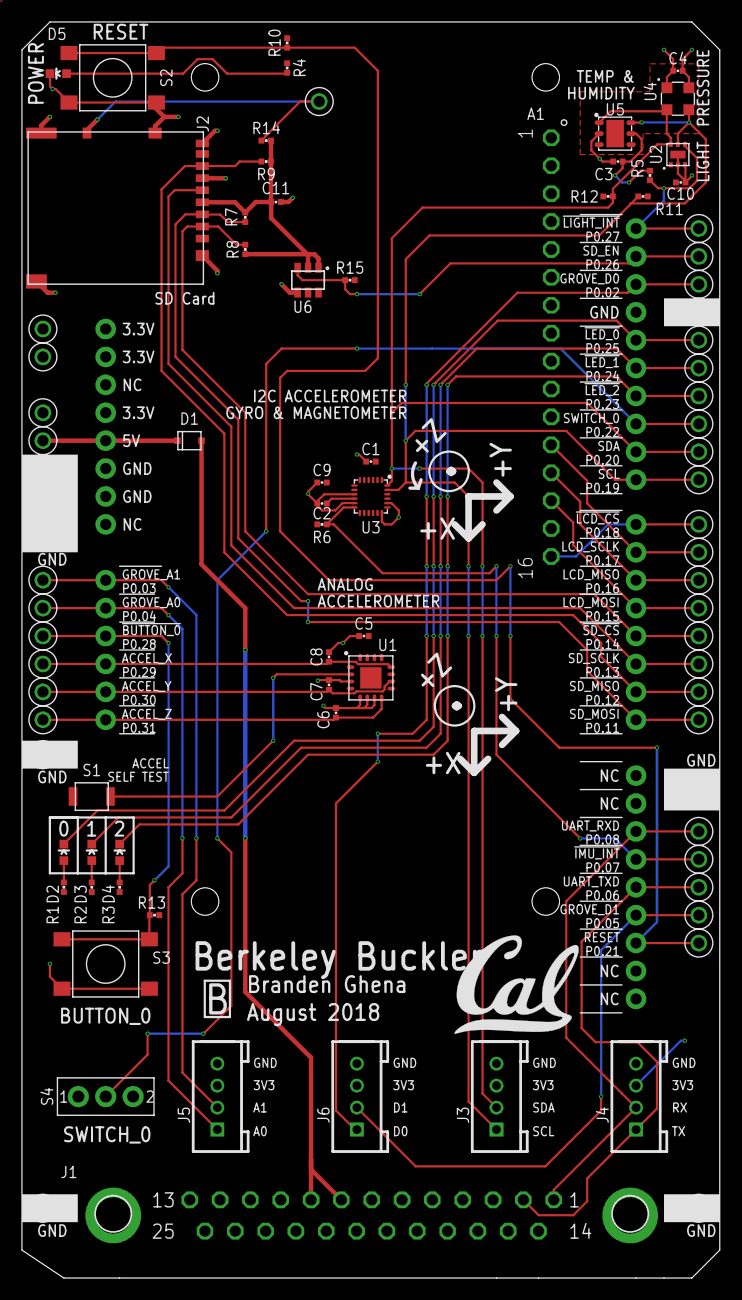
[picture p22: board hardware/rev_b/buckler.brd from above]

Board: 2 copper layers, 63.5 x 114.3 mm, 91 parts (0 on the bottom side), 40 nets.

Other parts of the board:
U$5: UCB_CAL_350MIL

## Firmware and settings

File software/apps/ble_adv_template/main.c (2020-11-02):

// BLE advertisement template
//
// Advertises device name: EE149

#include <stdbool.h>
#include <stdint.h>
#include "nrf.h"
#include "app_util.h"
#include "nrf_twi_mngr.h"
#include "nrf_log.h"
#include "nrf_log_ctrl.h"
#include "nrf_log_default_backends.h"

#include "buckler.h"
#include "simple_ble.h"

#include "opt3004.h"

// Create a timer
APP_TIMER_DEF(adv_timer);

// I2C manager
NRF_TWI_MNGR_DEF(twi_mngr_instance, 5, 0);

// Intervals for advertising and connections
static simple_ble_config_t ble_config = {
        // c0:98:e5:49:xx:xx
        .platform_id       = 0x49,    // used as 4th octect in device BLE address
        .device_id         = 0x0000,  // TODO: replace with your lab bench number
        .adv_name          = "EE149", // Note that this name is not displayed to save room in the advertisement for data.
        .adv_interval      = MSEC_TO_UNITS(1000, UNIT_0_625_MS),
        .min_conn_interval = MSEC_TO_UNITS(500, UNIT_1_25_MS),
        .max_conn_interval = MSEC_TO_UNITS(1000, UNIT_1_25_MS),
};

void light_timer_callback() {
    printf("Light timer fired!\n");
    // TODO: implement this function!
    // Use Simple BLE function to read light sensor and put data in advertisement
}

/*******************************************************************************
 *   State for this application
 ******************************************************************************/
// Main application state
simple_ble_app_t* simple_ble_app;

int main(void) {
  ret_code_t error_code = NRF_SUCCESS;

  // Initialize

  // initialize RTT library
  error_code = NRF_LOG_INIT(NULL);
  APP_ERROR_CHECK(error_code);
  NRF_LOG_DEFAULT_BACKENDS_INIT();
  printf("Log initialized\n");

  // initialize i2c master (two wire interface)
  nrf_drv_twi_config_t i2c_config = NRF_DRV_TWI_DEFAULT_CONFIG;
  i2c_config.scl = BUCKLER_SENSORS_SCL;
  i2c_config.sda = BUCKLER_SENSORS_SDA;
  i2c_config.frequency = NRF_TWIM_FREQ_100K;
  error_code = nrf_twi_mngr_init(&twi_mngr_instance, &i2c_config);
  APP_ERROR_CHECK(error_code);

  opt3004_config_t config = {
    .range_number = OPT3004_AUTORANGE,
    .conversion_time = OPT3004_CONVERSION_100MS,
    .latch_interrupt = 1,
    .interrupt_polarity = OPT3004_INTERRUPT_ACTIVE_LO,
    .fault_count = OPT3004_FAULT_COUNT_1,
  };

  // initialize opt3004 driver
  opt3004_init(&twi_mngr_instance);
  error_code = opt3004_config(config);
  // set up opt3004 to read continuously
  opt3004_continuous();

  printf("opt3004 initialized: %ld\n", error_code);


  // Setup BLE
  simple_ble_app = simple_ble_init(&ble_config);

  // TODO replace this with advertisement sending light data
  simple_ble_adv_only_name();

  // Set a timer to read the light sensor and update advertisement data every second.
  app_timer_init();
  app_timer_create(&adv_timer, APP_TIMER_MODE_REPEATED, (app_timer_timeout_handler_t) light_timer_callback);
  app_timer_start(adv_timer, APP_TIMER_TICKS(1000), NULL); // 1000 milliseconds

  while(1) {
    // Sleep while SoftDevice handles BLE
    power_manage();
  }
}

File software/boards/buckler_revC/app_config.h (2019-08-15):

// application-specific configuration
// augments the base configuration in sdk/<SDK>/config/<IC>/config/sdk_config.h

#pragma once

#define SIMPLE_BLE_ENABLED 1

#define BLE_ADVERTISING_ENABLED 1
#define NRF_BLE_CONN_PARAMS_ENABLED 1
#define NRF_BLE_GATT_ENABLED 1
#define NRF_BLE_QWR_ENABLED 1
#define BLE_ECS_ENABLED 1

#define BLE_LBS_ENABLED 1
#define BLE_NUS_ENABLED 1

#define NRF_CRYPTO_BACKEND_CIFRA_ENABLED 1
#define NRF_CRYPTO_BACKEND_MBEDTLS_ENABLED 1
#define NRF_CRYPTO_BACKEND_NRF_HW_RNG_ENABLED 1

#define GPIOTE_ENABLED 1
#define GPIOTE_CONFIG_NUM_OF_LOW_POWER_EVENTS 4
#define NRFX_GPIOTE_ENABLED 1

#define NRFX_RNG_ENABLED 1
#define RNG_ENABLED 1

#define NRFX_SAADC_ENABLED 1
#define SAADC_ENABLED 1
#define SAADC_CONFIG_LP_MODE 1

#define NRFX_SPIM_ENABLED 1
#define NRFX_SPIM1_ENABLED 1
#define NRFX_SPI_ENABLED 1
#define NRFX_SPI1_ENABLED 1
#define SPI_ENABLED 1
#define SPI1_ENABLED 1

#define APP_SDCARD_ENABLED 1

#define NRF_CLOCK_ENABLED 1
#define NRFX_CLOCK_ENABLED 1

#define NRFX_TIMER_ENABLED 1
#define NRFX_TIMER0_ENABLED 1
#define NRFX_TIMER1_ENABLED 1
#define TIMER_ENABLED 1
#define TIMER_DEFAULT_CONFIG_BIT_WIDTH 3
#define TIMER0_ENABLED 1
#define TIMER1_ENABLED 1
#define APP_TIMER_ENABLED 1
#define APP_TIMER_KEEPS_RTC_ACTIVE 1

#define NRFX_UARTE_ENABLED 1
#define NRFX_UART_ENABLED 1
#define UART_ENABLED 1
#define UART0_ENABLED 1
#define APP_UART_ENABLED 1
#define HCI_UART_TX_PIN 6
#define HCI_UART_RX_PIN 8

#define NRFX_TWIM_ENABLED 1
#define NRFX_TWI_ENABLED 1
#define TWI_ENABLED 1
#define TWI0_ENABLED 1
#define TWI0_USE_EASY_DMA 1
#define NRF_TWI_MNGR_ENABLED 1

#define APP_FIFO_ENABLED 1
#define APP_SCHEDULER_ENABLED 1

#define CRC16_ENABLED 1

#define NRF_FSTORAGE_ENABLED 1
#define FDS_ENABLED 1
#define FDS_VIRTUAL_PAGES 10
#define FDS_OP_QUEUE_SIZE 10

#define MEM_MANAGER_ENABLED 1

#define NRF_QUEUE_ENABLED 1

#define NRF_PWR_MGMT_ENABLED 1
#define NRF_PWR_MGMT_CONFIG_FPU_SUPPORT_ENABLED 1

#define RETARGET_ENABLED 0

#define BUTTON_ENABLED 1

#define NRFX_PWM_ENABLED 1
#define NRFX_PWM0_ENABLED 1
#define NRFX_PWM1_ENABLED 1
#define NRFX_PWM2_ENABLED 1
#define PWM_ENABLED 1
#define PWM0_ENABLED 1
#define PWM1_ENABLED 1
#define PWM2_ENABLED 1
#define APP_PWM_ENABLED 1
#define LOW_POWER_PWM_ENABLED 1
#define NRFX_PPI_ENABLED 1
#define PPI_ENABLED 1

#define NRF_SECTION_ITER_ENABLED 1

#define NRF_LOG_ENABLED 1
#define NRF_LOG_BACKEND_UART_ENABLED 0
#define NRF_LOG_BACKEND_RTT_ENABLED 1
#define NRF_LOG_USES_RTT 1
#define NRF_LOG_DEFERRED 0
#define NRF_LOG_STR_PUSH_BUFFER_SIZE 128

#define HARDFAULT_HANDLER_ENABLED 1
#define HARDFAULT_HANDLER_GDB_PSP_BACKTRACE 0

#define NRF_SERIAL_ENABLED 1

#define NRF_SDH_ENABLED 1
#define NRF_SDH_BLE_ENABLED 1
#define NRF_SDH_BLE_GAP_DATA_LENGTH 251
#define NRF_SDH_BLE_PERIPHERAL_LINK_COUNT 1
#define NRF_SDH_BLE_GATT_MAX_MTU_SIZE 247
#define NRF_SDH_BLE_VS_UUID_COUNT 10
#define NRF_SDH_SOC_ENABLED 1

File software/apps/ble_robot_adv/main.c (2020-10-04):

// Robot Template app
//
// Framework for creating applications that control the Kobuki robot

#include <math.h>
#include <stdbool.h>
#include <stdint.h>
#include <stdio.h>

#include "app_error.h"
#include "app_timer.h"
#include "nrf.h"
#include "nrf_delay.h"
#include "nrf_gpio.h"
#include "nrf_log.h"
#include "nrf_log_ctrl.h"
#include "nrf_log_default_backends.h"
#include "nrf_pwr_mgmt.h"
#include "nrf_drv_spi.h"

#include "buckler.h"
#include "display.h"
#include "kobukiActuator.h"
#include "kobukiSensorPoll.h"
#include "kobukiSensorTypes.h"
#include "kobukiUtilities.h"
#include "lsm9ds1.h"
#include "simple_ble.h"

#include "states.h"

// I2C manager
NRF_TWI_MNGR_DEF(twi_mngr_instance, 5, 0);

// global variables
KobukiSensors_t sensors = {0};

// Intervals for advertising and connections
static simple_ble_config_t ble_config = {
        // c0:98:e5:49:xx:xx
        .platform_id       = 0x49,    // used as 4th octect in device BLE address
        .device_id         = 0x0000, // TODO: replace with your lab bench number
        .adv_name          = "KOBUKI", // used in advertisements if there is room
        .adv_interval      = MSEC_TO_UNITS(100, UNIT_0_625_MS),
        .min_conn_interval = MSEC_TO_UNITS(100, UNIT_1_25_MS),
        .max_conn_interval = MSEC_TO_UNITS(200, UNIT_1_25_MS),
};

simple_ble_app_t* simple_ble_app;

void print_state(states current_state){
	switch(current_state){
	case OFF:
		display_write("OFF", DISPLAY_LINE_0);
		break;
	case DRIVING:
		display_write("DRIVING", DISPLAY_LINE_0);
		break;
    }
}

int main(void) {
  ret_code_t error_code = NRF_SUCCESS;

  // initialize RTT library
  error_code = NRF_LOG_INIT(NULL);
  APP_ERROR_CHECK(error_code);
  NRF_LOG_DEFAULT_BACKENDS_INIT();
  printf("Log initialized!\n");

  // Setup BLE
  simple_ble_app = simple_ble_init(&ble_config);

  // Start Advertising
  simple_ble_adv_only_name();

  // initialize LEDs
  nrf_gpio_pin_dir_set(23, NRF_GPIO_PIN_DIR_OUTPUT);
  nrf_gpio_pin_dir_set(24, NRF_GPIO_PIN_DIR_OUTPUT);
  nrf_gpio_pin_dir_set(25, NRF_GPIO_PIN_DIR_OUTPUT);

  // initialize display
  nrf_drv_spi_t spi_instance = NRF_DRV_SPI_INSTANCE(1);
  nrf_drv_spi_config_t spi_config = {
    .sck_pin = BUCKLER_LCD_SCLK,
    .mosi_pin = BUCKLER_LCD_MOSI,
    .miso_pin = BUCKLER_LCD_MISO,
    .ss_pin = BUCKLER_LCD_CS,
    .irq_priority = NRFX_SPI_DEFAULT_CONFIG_IRQ_PRIORITY,
    .orc = 0,
    .frequency = NRF_DRV_SPI_FREQ_4M,
    .mode = NRF_DRV_SPI_MODE_2,
    .bit_order = NRF_DRV_SPI_BIT_ORDER_MSB_FIRST
  };
  error_code = nrf_drv_spi_init(&spi_instance, &spi_config, NULL, NULL);
  APP_ERROR_CHECK(error_code);
  display_init(&spi_instance);
  printf("Display initialized!\n");

  // initialize i2c master (two wire interface)
  nrf_drv_twi_config_t i2c_config = NRF_DRV_TWI_DEFAULT_CONFIG;
  i2c_config.scl = BUCKLER_SENSORS_SCL;
  i2c_config.sda = BUCKLER_SENSORS_SDA;
  i2c_config.frequency = NRF_TWIM_FREQ_100K;
  error_code = nrf_twi_mngr_init(&twi_mngr_instance, &i2c_config);
  APP_ERROR_CHECK(error_code);
  lsm9ds1_init(&twi_mngr_instance);
  printf("IMU initialized!\n");

  // initialize Kobuki
  kobukiInit();
  printf("Kobuki initialized!\n");

  states state = OFF;

  // loop forever, running state machine
  while (1) {
    // read sensors from robot
    kobukiSensorPoll(&sensors);

    // TODO: complete state machine
    switch(state) {
      case OFF: {
        print_state(state);

        // transition logic
        if (is_button_pressed(&sensors)) {
          state = DRIVING;
          lsm9ds1_start_gyro_integration();
        } else {
          state = OFF;
          // perform state-specific actions here
          kobukiDriveDirect(0, 0);
        }
        break; // each case needs to end with break!
      }
      case DRIVING: {
        print_state(state);

        // transition logic
        if (is_button_pressed(&sensors)) {
          lsm9ds1_stop_gyro_integration();
          state = OFF;
        } else {
          state = DRIVING;
          // perform state-specific actions here
          uint16_t encoder = sensors.leftWheelEncoder;
          float angle = lsm9ds1_read_gyro_integration().z_axis;
          simple_ble_adv_manuf_data((uint8_t*) &angle, sizeof(angle));
          kobukiDriveDirect(0, 100);
        }
        break; // each case needs to end with break!
      }
    }
  }
}

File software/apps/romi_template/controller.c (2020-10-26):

#include <math.h>
#include <stdio.h>
#include "controller.h"
#include "kobukiSensorTypes.h"
#include "display.h"

// configure initial state
KobukiSensors_t sensors = {0};
uint16_t previous_encoder = 0;
float distance = 0;

static float measure_distance(uint16_t current_encoder, uint16_t previous_encoder) {
  const float CONVERSION = 0.00065;

  float result = 0.0;
  if (current_encoder >= previous_encoder) {
    result = (float)current_encoder - (float)previous_encoder;
  } else {
    result = (float)current_encoder + (0xFFFF - (float)previous_encoder);
  }
  return result = result * CONVERSION;
}

robot_state_t controller(robot_state_t state) {
  // read sensors from robot
  kobukiSensorPoll(&sensors);

  // delay before continuing
  // Note: removing this delay will make responses quicker, but will result
  //  in printf's in this loop breaking JTAG
  //nrf_delay_ms(1);

  char buf[16];
  snprintf(buf, 16, "%f", distance);
  display_write(buf, DISPLAY_LINE_1);

  // handle states
  switch(state) {
    case OFF: {
      // transition logic
      if (is_button_pressed(&sensors)) {
        state = DRIVING;
        previous_encoder = sensors.leftWheelEncoder;
      } else {
        // perform state-specific actions here
        display_write("OFF", DISPLAY_LINE_0);
        kobukiDriveDirect(0,0);
        state = OFF;
      }
      break; // each case needs to end with break!
    }

    case DRIVING: {
      // transition logic
      if (is_button_pressed(&sensors)) {
        state = OFF;
      } else if (distance >= 1) {
        state = OFF;
      } else {
        // perform state-specific actions here
        display_write("DRIVING", DISPLAY_LINE_0);
        kobukiDriveDirect(100,100);
        uint16_t current_encoder = sensors.leftWheelEncoder;
        distance = measure_distance(current_encoder, previous_encoder);
        state = DRIVING;
      }
      break; // each case needs to end with break!
    }
  }

  // add other cases here
  return state;
}

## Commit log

2018-07-29 Checkpoint. Working on schematic
    [buckler.brd, buckler.sch]
2018-08-02 Checkpoint. Done with schematic
    [buckler.brd, buckler.sch]
2018-08-02 Checkpoint. 50 airwares remaining!
    [buckler.brd, buckler.sch]
2018-08-02 Routing complete!!
    [buckler.brd, buckler.sch]
2018-08-02 Renumber script, plus some manual tweaks
    [buckler.brd, buckler.sch]
2018-08-02 Checkpoint, adding part numbers
    [buckler.brd, buckler.sch]
2018-08-02 Finished add part numbers for everything
    [buckler.brd, buckler.sch]
2018-08-03 Silkscreen complete
    [buckler.brd, buckler.sch]
2018-08-03 Finished with schematic and layout for rev A
    [buckler.brd, buckler.sch]
2018-08-03 Final revisions and fabrication files
    [buckler.brd, buckler.sch, buckler_bom.csv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]
2018-08-08 Checkpoint. Working on Rev B
    [buckler.brd, buckler.sch]
2018-08-08 Routing complete
    [buckler.brd, buckler.sch]
2018-08-08 Finished with revision B
    [buckler.brd, buckler.sch, buckler_bom.xlsx]
2018-08-08 Files for assembly
    [buckler_bom.csv]
2018-08-14 Explanations to assembler
2018-08-14 Example applications (currently using RevA hardware)
2018-08-15 Analog accelerometer sampling application
2018-08-16 working kobuki driver
2018-08-16 I2C IMU application!
2018-08-16 remove all the printing
2018-08-16 fix battery voltage sensing
2018-08-16 Fix mistake in uart pin config
    [app_config.h]
2018-08-16 add integration to the MPU driver. requires timer added to app config
2018-08-16 add the square drive with external IMU
2018-08-17 Add error handling. Pull nrf5x-base up to date
    [app_config.h]
2018-08-17 add a working display dirver
    currently can only be tested on the 52840, but I have no
    reason to believe it won't work once the new rev comes in
    [app_config.h, main.c]
2018-08-17 now compiling, but it won't run
    [main.c]
2018-08-23 Remove extraneous code from accelerometer app
2018-08-24 Upgrade to never buffer printf
2018-08-24 Update pins configurations to Buckler revB
2018-08-25 changed library structure to include boards.h, added SD card app
2018-08-25 Fix reversed tx/rx for kobuki on Rev B
    [buckler.h]
2018-08-26 Buckler testing app
2018-09-03 add interrupt base application
2018-09-03 add software interrupt and handler
2018-09-10 add prototype code for the virtual timers lab
2018-09-10 Updated ADC comments from a while ago
2018-09-10 Cleanup on virtual timers stub
2018-09-10 Last tweak to timer stub code
2018-09-18 Update IMU library
2018-11-04 Add example repo for submoduling buckler
2018-11-08 Light sensor driver!!
2018-11-08 Add PWM support
2018-11-12 BLE Service Example
    This is a huge hack for now because _something_ is wrong with Simple BLE
    connections that I'm finding impossible to debug. This example is good
    enough for projects to use (even if it ends up having a lot of random
    initialization code that I've been trying to hide away).
    [main.c]
2018-11-15 Add I2C sensor connection to service example
2019-08-03 Update buckler to use new nrf52x repo
    Fix boards to use nordic's process. Update log defines to use
    ringbuffer.
    [app_config.h]
2019-08-07 Add template for BLE transmit tx app
    First part of new wireless lab
    Add python script
2019-08-15 Fix Kobuki UART
    Previous implementation used deprecated app_uart_put in a while loop.
    When using a softdevice, bytes could be dropped occasionally resulting
    in an incorrect length read, leading to a hardfault. New implementation
    uses nordic's serial library. BLE + Kobuki work now.
    [app_config.h]
2019-08-28 fix interrupt
2019-08-30 fix warnings for travis errors
    [main.c]
2019-09-04 slow down accelerometer printing
2019-09-22 shorter dely so kobuki responds
    [main.c]
2019-09-26 Rehaul BLE lab materials
    Add python scripts for basically every part
    Fix missing initialization code for service template
    Specify UUIDs for examples + scripts
    [main.c]
2019-09-28 drive forward now expects wheel speeds
2019-10-08 Fix compile error for service example
    [main.c]
2019-10-16 Fix missing RTT for adv listen example
    Remove notification suggestion
    [main.c]
2019-10-16 fix off by one (hex is hard)
    [main.c]
2019-12-16 Shorten UART rx/tx timeouts
2020-07-23 First commit, rev_c
    [buckler.brd, buckler.sch, buckler_bom.csv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]
2020-07-23 Address problems in #2
    Reroute light, temp/hum, pressure sensors to make room for IC number
    labels. Rename 3v3->VCC. Flip UART RX/TX on DB25 connector. Move gyro
    axis label out from under LCD screen.
    [buckler.brd, buckler.sch]
2020-07-23 Add silk lines to clarify testpoint connections to header
    [buckler.brd]
2020-07-27 swap hi/lo switch label
    [buckler.brd]
2020-07-28 Use actual parts instead of test points
    Name nrf52dk headers too.
    [buckler.brd, buckler.sch, buckler_bom.csv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]
2020-07-28 renumber headers
    [buckler.brd, buckler.sch, buckler_bom.csv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]
2020-08-01 replace digital acc with lsm9ds1tr
    [buckler.brd, buckler.sch]
2020-08-03 add OPT light sensor
    [buckler.brd, buckler.sch]
2020-08-03 zip it up for quote
    [buckler.brd, buckler.sch, buckler_bom.csv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]
2020-08-28 Start drivers for new sensors
    Able to talk to new accelerometer
2020-08-30 Got basic accelerometer function working on IMU
2020-08-31 Get gyro integration working like with mpu
    Still need to clean up and update example apps
2020-09-14 increase delay to avoid clogging jtag
    [main.c]
2020-09-14 Clean up opt driver a bit
2020-09-30 changed bucker-kobuki protocol implementation to conform to protocol
2020-10-02 reverse TX/RX in board def
    [buckler.h]
2020-10-02 remove prints in lsm
2020-10-02 Init/Deinit UART for every transaction
    Prevent UART buffer overflow if too many messages. Only init uart if we
    are using it.
    [main.c]
2020-10-05 define uart (un)init
2020-11-02 Change adv example to use new opt3004 sensor
2021-09-10 use correct board name for revc makefile

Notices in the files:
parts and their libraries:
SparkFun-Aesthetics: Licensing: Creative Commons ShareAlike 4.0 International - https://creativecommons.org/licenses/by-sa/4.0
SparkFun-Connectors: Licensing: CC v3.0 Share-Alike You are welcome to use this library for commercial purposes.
